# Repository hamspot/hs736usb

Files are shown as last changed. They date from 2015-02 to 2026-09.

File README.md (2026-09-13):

# Ham Spot Inc
##  HS-736USB
http://hamspot.com/33-prod-hs-736usb

### FT-736R to HRD USB Interface
The Yaesu FT-736R remains a popular satellite ground station transceiver.  However some modern computer software is not compatible with the CAT interface on the FT-736R.  Ham Radio Deluxe, in particular, does not support the FT-736R.  Ham Radio Deluxe does support the Yaesu FT-847 which has similar features.  We can solve this incompatibility by programming a CAT interface to present a FT-847 to the PC and emulate the new commands not supported on the FT-736R.  

Features not present on the FT-736R are ignored.  Memory channels are not supported and the radio must be set to VFO, also satellite mode must be set to VFO, before enabling CAT control of the radio.  1240 MHz is mapped to 240 MHz because the FT-847 does not have 4 MHz digits.

### Credits
A short history, archived Comcast pages, and the original downloads are in **[Archives/README.md](Archives/README.md)**.

The concept was developed by Dave, KA6BFB in 2010 (Windows VB proof of concept, virtual serial ports): [Archives/Software.md](Archives/Software.md).

The hardware version was developed by Chuck, N6BIL (PIC18F14K50, GPL source and Eagle CAD): [Archives/Hardware.md](Archives/Hardware.md).

Ham Spot Inc based the HS-736USB on their great work and thanks them immensely for their hard work on solving a challenging problem! The goal of Ham Spot Inc is that if this interface is popular we will develop similar interfaces for other older rigs which are also not supported by HRD. Specifically in mind are the FT-757GXII, FT-890 and various Icom and Kenwood radios. There will likely be firmware updates to this hardware available on the http://hamspot.com/ website in the future. If you have a PIC programmer the chip has been socketed to allow you to flash new firmware or easily replace the device. If not, there will be made available an inexpensive preprogrammed chip that you can plugin to upgrade the firmware or convert the FT-736USB to another model Yaesu rig as they become supported.

### Arduino / ATmega328P port

An Arduino Uno/Nano port of the CAT translator lives in **[Arduino/](Arduino/)**. It keeps the PIC 847↔736 mapping, adds native-736 passthrough (pin A1 or a CAT opcode), PTT/band GPIO, and an S-meter PWM. The PIC firmware in `Firmware/` is unchanged.

```
arduino-cli compile --fqbn arduino:avr:nano Arduino/firmware
cd Arduino && test/run_suite.sh
```

See `Arduino/README.md`, `Arduino/docs/WIRING.md`, and `Arduino/docs/PROTOCOLS.md`. Operating manuals for both the PIC cabinet and the Arduino port are in [`Manual/`](Manual/).

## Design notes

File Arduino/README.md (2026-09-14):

# Arduino / ATmega328P port

Drop-in replacement for the PIC18F14K50 HS-736USB on an Arduino Uno or Nano: the PC speaks **Yaesu FT-847 CAT** (or native **FT-736R** CAT); the box drives the FT-736R CAT jack at 4800 8N2 TTL.

The original PIC firmware, Eagle files, and manual stay in `Firmware/`, `Hardware/`, and `Manual/` at the repo root. This directory is GPL-3 like the rest of the project (N6BIL translator in `Firmware/Source/main.c`).

## Build

```
arduino-cli compile --fqbn arduino:avr:nano Arduino/firmware
arduino-cli upload --fqbn arduino:avr:nano -p /dev/ttyUSB0 Arduino/firmware
```

From this directory, `firmware` is enough. Libraries: **AltSoftSerial**, **Wire**. LCD is a bare HD44780 on an MCP23017 (default) or MCP23008 (`-DHS736_MCP=8`), not an I2C backpack. `-DHS736_MCP=0` omits LCD, encoder, and I2C. See `docs/WIRING.md`.

Host: **4800 8N2**, no handshake. Default dialect is FT-847 (Hamlib `-m 1001`). Pin **A1** low, or CAT `A5 73 36 02 FC`, selects native 736 (`-m 1010`).

- Operating manual (PDF, with the PIC booklet): `../Manual/HS-736USB-Operating-Manual.pdf`
- Wiring: `docs/WIRING.md`
- 847 vs 736 dialects: `docs/PROTOCOLS.md`
- Radio connectors (manual errors): `docs/CONNECTIONS.md`
- Design notes: `PLAN.md`

```
Arduino/test/run_suite.sh
Arduino/test/run_suite.sh /dev/ttyUSB0
```

Run the suite from the `Arduino/` directory (paths are relative to that folder).

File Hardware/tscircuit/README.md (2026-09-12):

# HS-736USB Nano carrier (tscircuit)

Arduino Nano plugs into `JP_L` / `JP_R`. This board is the I/O carrier
(CAT, PTT MOSFET, RCA sense, dialect jumper, LCD, band, PWM). The MCU
is not redrawn.

CAT DIN pin 6 (+13.8 V) is not connected. Power is Nano USB 5 V.

## CLI

IndianaDell installs tscircuit under `~/.local` (`bin/tsci` runs `node`
on `cli.mjs`). The npm shebang is bun, and node cannot load `.tsx`.

From this directory, use the project CLI with bun:

```bash
BUN=/tmp/bunpkg/node_modules/bun/bin/bun.exe
# npm install --prefix /tmp/bunpkg bun  (Linux binary is named bun.exe)

"$BUN" node_modules/tscircuit/cli.mjs check netlist
"$BUN" node_modules/tscircuit/cli.mjs check schematic-placement
"$BUN" node_modules/tscircuit/cli.mjs check placement
"$BUN" node_modules/tscircuit/cli.mjs build --pcb-svgs --schematic-svgs --kicad-project
"$BUN" node_modules/tscircuit/cli.mjs check shorts
inkscape dist/index/pcb.svg --export-type=png --export-filename=dist/index/pcb.png --export-dpi=1200
inkscape dist/index/schematic.svg --export-type=png --export-filename=dist/index/schematic.png --export-dpi=1200
```

Do not `tsci push` or order boards unless asked.

`<schematicsheet>` is omitted on purpose: with it, `kicad_sch` export
is a hierarchical stub (`main.kicad_sch` never written). Sections
still group the schematic.

Known warnings: builtin symbols missing `{REFDES}` text; SOD-123 has
no 3D model on the tscircuit CDN.

Outputs: `dist/index/pcb.png`, `dist/index/schematic.png`,
`dist/index/kicad/`.

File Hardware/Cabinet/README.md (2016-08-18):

# Laser Cut or 3D Printed Cabinet
Inside dimensions 28.73mm x 16mm x 43.73mm

* v1 is Hammond project enclosure.
* v2 is .125" Laser cut acrylic or hardboard.
* v2.1 is a 3D printed case.

json files are for basic dimensions and were generated with http://www.makercase.com/
svg or ai files have been edited to include holes for panel connectors, screws, feet, etc.

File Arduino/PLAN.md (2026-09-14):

# HS-736: PIC18F14K50 → ATmega328 Arduino port

Port [hamspot/hs736usb](https://github.com/hamspot/hs736usb) so an ATmega328P Arduino (Uno/Nano class) sits between a PC and a Yaesu FT-736R: the PC talks **FT-847 CAT** (read/write, Hamlib/HRD/SatPC32), the box translates and drives the **FT-736R CAT** jack (mostly write-only frequency/mode; squelch and S-meter can be read).

Original firmware is the behavioral spec. [Hamlib](https://github.com/Hamlib/Hamlib) `rigs/yaesu/ft847.c` and `ft736.c` are the protocol reference (local copy: `/home/user/Documents/Hamlib`).

License: original CAT translator in `Firmware/Source/main.c` (`To736` / `ProcessIO`, Albert C. Jones / N6BIL, 2010) is **GPL-3**. This port is a derivative and stays GPL-3. Microchip’s USB stack in that file is **not** copied.

---

## What the PIC actually does

USB CDC (VID 0x04D8 / PID 0x000A, generic CDC) ↔ PIC UART TTL:

| PIC pin | Function |
| --- | --- |
| RB7 | UART TX → radio S-OUT pad |
| RB5 | UART RX ← radio S-IN pad |
| RC0/RC1 | LEDs |
| — | Radio UART **fixed 4800**, 8 data. Host USB baud is independent (CDC). |

`ProcessIO()` is the whole product (excerpt in `upstream/ProcessIO-excerpt.c`):

1. Collect host bytes into a 5-byte Yaesu block (`cmd[0..3]` params, `cmd[4]` opcode).
2. **Reads** (never go to the 736): `0x03` / `0x13` / `0x23` freq+mode, `0xE7` RX status, `0xF7` TX status — reply from RAM caches.
3. **Writes** translated to the 736, 5 bytes, wait for TX empty. PIC used **no** 50–200 ms inter-byte delay; this port does (CAT spec).
4. PIC forwarded UART bytes from the 736 to USB. v1 of this port does **not** splice 736 frames onto the 847 stream.

Caches default to 145.0000 MHz FM (`{0x14,0x50,0x00,0x00,0x08}`).

On **CAT ON** (`0x00`) the adapter also forces 145.0000 + FM onto the 736 so host and radio start aligned. CAT ON on the 736 **locks the front panel**.

---

## Protocol (Hamlib + PIC)

Both radios use 5-byte blocks, opcode last, 4800 8N2. FT-736 manual: **50–200 ms between bytes**. Hamlib: `write_delay` 50 ms (847) / 30 ms (736).

### Opcode map (host 847 → radio 736)

| Host opcode | Meaning (ft847.c) | Action |
| --- | --- | --- |
| `00` | CAT ON | Send as-is; then set cached main freq (`01`) and FM (`08 00 00 00 07`) |
| `80` | CAT OFF | Send as-is |
| `08` / `88` | PTT on / off | Send as-is; update TX/RX status cache |
| `01` | Set main freq | Cache 4 BCD bytes; 23 cm remap; send opcode `01` |
| `11` | Set SAT RX freq | Cache; remap opcode **`1E`** (736 full-duplex RX freq) |
| `21` | Set SAT TX freq | Cache; remap opcode **`2E`** |
| `03` / `13` / `23` | Get freq+mode main / sat RX / sat TX | Reply 5 bytes from cache |
| `07` / `17` / `27` | Set mode main / sat RX / sat TX | Forward; store mode in cache byte 4. 736 has no AM/CWR |
| `4E` | Sat mode ON | Remap to **`0E`** (736 “full duplex on”) |
| `8E` | Sat mode OFF | Send `8E`; restore main freq with `01` |
| `09` | Repeater shift (HRD/PIC) | `cmd[4] = cmd[0]` then send (`09` minus, `49` plus, `89` simplex) |
| `49` / `89` | Repeater plus / simplex (Hamlib 847) | Forward as-is. 736 simplex is **`89` not `88`** (`88` is PTT off) |
| `0A` | CTCSS/DCS mode | `2A` (847 ENC/DEC) → opcode `0A`; `0A` (847 DCS) → **drop** (PIC sent `00` = CAT ON; that is a bug); `4A`/`8A` forwarded as opcode |
| `0B` | CTCSS tone | Opcode **`FA`**; index PIC `Tone[38]`. If `cmd[0] > 31`, index `cmd[0]-26`. Clamp if out of range |
| `E7` / `F7` | Get RX / TX status | Reply from cache; do **not** forward as 847 status |
| `F9` | Repeater offset | Forward as-is (736 supports it; PIC dropped it) |
| `1A`/`2A`/`1B`/`2B`/`0C`/`1C`/`2C` | Sat CTCSS / DCS | Drop (no 736 DCS; sat CTCSS later) |

BCD frequency is 8 packed digits, **10 Hz units**, MSB first (Hamlib `to_bcd_be(cmd, freq/10, 8)`).

### 23 cm (1240 MHz)

FT-847 has no 4th MHz digit, so the host shows **240 MHz**. PIC: if `cmd[0]` is `0x24`..`0x30`, add `0xA0` on the **radio copy only** (`0x24` → `0xC4`). Cache returned to the PC stays 240 MHz.

Hamlib native 736 uses `(cmd[0] & 0x0f) | 0xc0` after encoding the true 1.24 GHz value (`0xC2 0x40 …` for 1240.0000). **v1 matches PIC**. Treat Hamlib’s encoding as a 23 cm bench check.

### Status reads

FT-736 **cannot** return frequency or mode. Hamlib `ft736_get_freq` is cache-only.

736 **can** return meters: after `E7`/`F7` it sends five bytes (four copies of squelch or S-meter plus echoed opcode).

FT-847 status is **one** byte:

- `E7` RX: bit7 = squelch closed (DCD off), bits0–4 = S-meter dots
- `F7` TX: bit7 = 1 means RX (`PTT_OFF`), bits0–4 = PO/ALC

v1 replies (Hamlib + HRD):

- `03`/`13`/`23`: 5-byte cache (BCD + mode)
- `E7`/`F7`: 5-byte buffer, **byte0 847-coded** (PIC PTT/squelch bits). Extra four bytes keep HRD happy; Hamlib reads 1 byte then flushes.

Unknown host opcodes: drop. Do not echo garbage to the 736.

### Framing

5-byte assembler: append host bytes; dispatch at 5; keep remainder. If a gap **> 250 ms**, discard partial frame (CAT inter-byte max is 200 ms — protocol timeout, not a poll loop).

---

## Bugs in the PIC firmware

Evidence is `upstream/ProcessIO-excerpt.c` (from hamspot `Firmware/Source/main.c`). These are defects in the translator, not “736 limitations.” This port fixes the ones marked **fixed**.

### 1. DCS ON is rewritten as CAT ON — **fixed**

```
cmd[4] = cmd[0];
if (cmd[0] == 0x2A) cmd[4] = 0x0A;   /* 847 ENC/DEC -> 736 TSQL */
if (cmd[0] == 0x0A) cmd[4] = 0x00;   /* 847 DCS ON  -> opcode 00 */
To736();
```

FT-847 DCS on is `{0x0A, 0x00, 0x00, 0x00, 0x0A}` (Hamlib `FT_847_NATIVE_CAT_SET_DCS_ON_MAIN`). The PIC copies byte 0 into the opcode, then the second `if` overwrites that opcode with **`0x00` (CAT ON)**. The 736 has no DCS; the harm is not “ignore DCS,” it is **re-asserting CAT**, which locks the front panel again. This port **drops** 847 DCS instead of sending `00`.

### 2. `cmd[10]` overflows on a 64-byte USB packet — **fixed**

`cmd` is 10 bytes. `getsUSBUSART(..., 64)` can return up to 64. The copy loop is `cmd[psn] = RS232_Out_Data[x]; ++psn` with no cap. One full CDC packet writes off the end of `cmd` (and into whatever follows in `.udata`). This port accumulates one byte at a time into a 5-byte frame buffer.

### 3. At most one CAT command per USB packet; leftover 5-byte commands stall — **fixed**

After copying the whole packet, it dispatches **once** (`if (psn > 4)`), then:

```
if (psn > 5)
    for (x = 0; x < (psn - 5); ++x) cmd[x] = cmd[x+5];
if (psn > 4) psn = psn - 5;
RS232_Out_Data_Rdy = 0;
```

A 10-byte packet (two Yaesu blocks) runs the first command, rotates the second into `cmd[0..4]` with `psn == 5`, then **clears the “data ready” flag**. The second command sits until **another** USB packet arrives and the copy loop runs again. Hamlib usually sends one 5-byte block per write, so this often works; HRD bursts and back-to-back `rigctl` can stall a command. This port dispatches every complete 5-byte frame in the same `loop()`.

### 4. CTCSS `Tone[x]` has no range check — **fixed**

```
if (cmd[0] > 31) x = cmd[0] - 26;
else x = cmd[0];
cmd[0] = Tone[x];   /* Tone[38] */
```

Any host byte `>= 0x40` (64) yields `x >= 38` and reads off the end of `Tone[]`. This port drops the command if the index is out of range.

Related mismatch (not a bounds bug): the PIC treats byte 0 as an **HRD-style index** (0…31, then skip 26). Hamlib `ft847_set_ctcss_tone` sends **Yaesu CAT tone codes** (`0x3F`, `0x39`, … `0x00`), not 0-based indices. v1 keeps the PIC table so HRD behavior is unchanged; Hamlib CTCSS frequencies will still be wrong until a later Hamlib-code map is added. That is documented, not silently “fixed.”

### 5. No 50–200 ms inter-byte gap on the radio UART — **fixed**

`To736()` waits only for `TXSTA` shift-complete, then sends the next byte immediately. The FT-736R manual requires **50–200 ms between bytes** of a command block. Hamlib uses `write_delay` 30–50 ms for the same reason. Field units often still keyed the radio; this port enforces 50 ms because the spec says so, not because we guessed.

### 6. Radio RX is spliced onto the FT-847 USB stream

```
if (mDataRdyUSART()) {
    USB_Out_Buffer[NextUSBOut] = getcUSART();
    ++NextUSBOut;
    USB_Out_Buffer[NextUSBOut] = 0;
}
```

Any byte the 736 emits (squelch/S-meter replies, AQS, noise) is forwarded to the PC **in the middle of the 847 session**. Hamlib 847 then sees extra bytes before/after a 1-byte `E7` or a 5-byte `03` and can desynchronize. `NextUSBOut` is also incremented with **no cap** against `USB_Out_Buffer[]`. This port **discards** radio RX in v1 (freq/mode are cached; we do not query 736 `E7`/`F7` yet).

### 7. Hamlib repeater-shift opcodes `49` / `89` are ignored

PIC only handles opcode **`09`**, then replaces it with `cmd[0]` (HRD: minus/plus/simplex in byte 0). Hamlib 847 sends the shift **as the opcode**: `09` minus, `49` plus, `89` simplex (`ft847_set_rptr_shift`). Plus and simplex therefore never reach the 736. If HRD ever put **`88`** in byte 0 (736 manual typo for simplex; Hamlib 736 notes that `88` is PTT off), the PIC would send PTT off. This port forwards Hamlib `49`/`89` as-is and keeps the PIC `09`+param path.

### 8. CAT ON / sat-off clobber `cmd[]` after `To736()`

CAT ON sends the host `00` block, then **overwrites** `cmd[]` with cached freq and FM and sends those too. That is intended. Sat-off (`8E`) does the same for a follow-up `01`. Harmless if `To736` is synchronous (it is). Noted so the port’s three-frame result struct is not mistaken for a PIC bug.

### What we did not treat as bugs

- Caching freq/mode instead of reading the 736 — the radio cannot return them.
- Dummy `E7`/`F7` 5-byte replies — design for HRD; byte 0 happens to match 847 PTT/squelch bits.
- Dropping memory, AQS, DCS, sat CTCSS `1A`/`2A` — original README / no 736 feature.
- 23 cm `+ 0xA0` vs Hamlib `(bcd & 0x0f) | 0xc0` — two encodings; PIC’s is what HS-736USB shipped. v1 keeps PIC; bench on a 1.2 GHz module before changing.

---

## Hardware (ATmega328P)

The 328 has **one** hardware USART. On Uno/Nano that USART is the USB-serial bridge to the PC.

See `docs/WIRING.md` (Arduino, including accessory GPIO) and `docs/CONNECTIONS.md` (every FT-736R jack, with diagrams; CAT/DATA manuals are often wrong). Host settings: **Yaesu FT-847, 4800, 8N2, no handshake**.

Accessory GPIO (not 847 CAT): D2 PTT MOSFET (CAT PTT **or** A0 RCA sense, active low), D4–D7 one-hot 50/144/220/430, D10 CAT BUSY in, D3 S-meter PWM from real 736 `F7` polls (also cached into host `E7`). Optional MCP23017 or MCP23008 on A4/A5 (`HS736_MCP`): bare HD44780 + encoder. D13 dialect LED. **A1** (PCINT): HIGH = USB speaks FT-847, LOW = native FT-736. See `docs/PROTOCOLS.md` and `docs/WIRING.md`.

---

## Firmware layout

```
PLAN.md
README.md
LICENSE
upstream/                 # original README, LICENSE, ProcessIO excerpt
firmware/                 # Arduino sketch (folder name = sketch name)
  firmware.ino
  cat_frame.{h,cpp}
  cat_map.{h,cpp}
  radio_uart.{h,cpp}
docs/WIRING.md
docs/CONNECTIONS.md          # FT-736R front/rear pinouts + diagrams
docs/CAT.md
test/golden_vectors.py
test/test_cat_map.c
test/README.md
```

`loop()`:

1. Drain `Serial` into the frame assembler; on complete frame, dispatch.
2. Reads: write reply to USB.
3. Writes: queue radio bytes with 50 ms between bytes (FT-736 CAT spec).
4. Drain radio RX; v1 discards. Do not splice 736 frames onto the 847 stream.

---

## Testing

Host (no Arduino): `test/test_cat_map.c` + `test/golden_vectors.py`.

On hardware without the 736: `rigctl -m 1001 -r /dev/ttyUSB0 -s 4800` (Hamlib FT-847). After `F`/`M`, `f`/`m` should return the cache; `t` should not time out.

On the radio: CAT LED, VFO + sat VFO as in the original README.

---

## Out of scope (v1)

- Memory channels
- AQS / digital messages
- DCS
- Replacing Hamlib’s FT-736 backend (this box **is** an 847)
- Custom USB VID/PID
- Mega / 32U4 / ESP32
- New PCB

---

## Key decisions

| Decision | Why |
| --- | --- |
| Pretend 847 to the PC, 736 to the radio | Same product as HS-736USB; Hamlib 847 (`-m 1001`) has sat VFOs and reads |
| Faithful PIC opcode map, plus `F9` and Hamlib `49`/`89` | Known HRD behavior; Hamlib 736 confirms `1E`/`2E`/`0E`/`FA` |
| Cache freq/mode; 5-byte `E7`/`F7` with 847-coded byte0 | 736 has no freq read; HRD wanted 5 bytes; Hamlib 847 reads 1 byte then flushes |
| Hardware USART = PC, AltSoftSerial 8/9 = radio | Only one USART on 328; USB is the busy polling side |
| Host locked to 4800 8N2 | Uno UART baud is the CDC baud; 847/736 native rate |
| 50 ms radio inter-byte delay | FT-736 CAT spec 50–200 ms; PIC omitted it |
| Drop 847 DCS (`0A`/`0A`) instead of sending CAT ON | PIC bug: it rewrote the opcode to `00` |
| GPL-3, no Microchip USB sources | Translator is GPL; USB stack is not ours |

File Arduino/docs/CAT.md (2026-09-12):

# CAT opcode map

Default host dialect is FT-847 (Hamlib `-m 1001`). Pin **A1** low switches the USB dialect to native FT-736R (`-m 1010`). The radio is always driven with 736 CAT. Full tables and “what if I use the wrong dialect”: `docs/PROTOCOLS.md`.

Physical CAT jack: `docs/CONNECTIONS.md` and `docs/WIRING.md` (AMSAT pin numbers; some manuals are wrong).

See `PLAN.md` for the full opcode table, 23 cm mapping, status-byte layout, and the **Bugs in the PIC firmware** section.

Quick reference:

| Host (847) | Radio (736) |
| --- | --- |
| `00` CAT on | `00` then cached `01` freq and `07` FM |
| `80` CAT off | `80` |
| `08` / `88` PTT | same |
| `01` set freq | `01` (23 cm: first BCD `+ 0xA0` if 240–300 MHz) |
| `11` / `21` sat freq | `1E` / `2E` |
| `03` / `13` / `23` get freq | cache only (5 bytes) |
| `07` / `17` / `27` mode | same opcodes |
| `4E` sat on | `0E` full duplex on |
| `8E` sat off | `8E` then main `01` |
| `09` shift (HRD) | opcode = byte 0 |
| `49` / `89` shift (Hamlib) | forward |
| `0A` CTCSS mode | see PLAN.md; DCS dropped |
| `0B` tone | `FA` + PIC `Tone[]` |
| `E7` / `F7` status | 847: `E7` is last polled 736 S-meter (`F7`) as 847 RX status; `F7` is TX/PTT cache. 736 mode: forwarded to the radio |
| `F9` offset | forward |

Radio bytes are spaced **50 ms** apart (FT-736 manual: 50–200 ms per byte).

User opcode `A5 73 36 <sel> FC`: dialect source `00` jumper, `01` force 847, `02` force 736, `FF` cycle. See `docs/PROTOCOLS.md`.

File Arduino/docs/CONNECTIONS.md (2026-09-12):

# FT-736R connectors

Pinouts for **every** front- and rear-panel connector on the Yaesu FT-736R.

**Do not trust a random photocopy of the operating manual for CAT or DATA.** Some printings number DIN pins with Japanese/Yaesu order instead of IEC 60130, and some print the DATA jack tip/ring backwards. Sources used here are listed at the end of each section. Where sources disagree, both are shown and the one to wire is marked **use this**.

This file is about the **radio**. Arduino adapter wiring is in `docs/WIRING.md`.

---

## Manual errors (read this first)

| What is wrong | What is true | Source |
| --- | --- | --- |
| CAT pin numbers in some FT-736R manuals and an old Yaesu application note | Pin 1 GND, 2 serial **in** (to radio), 3 busy, 4 serial **out** (from radio), 5 NC, 6 +13.8 V. Pins are **not** numbered sequentially around the shell. | AMSAT W6SHP note |
| European DIN numbering vs Yaesu drawing | Same signals; the **printed pin numbers** on a European DIN drawing may not match the Yaesu drawing. Identify pins by the **keyway + AMSAT map** below, not by a number printed in a manual. | French OM translation note |
| DATA IN/OUT tip/ring reversed on some manuals | **Tip = received data (from radio). Ring = transmit data (to radio). Sleeve = GND.** | AMSAT W6SHP note; English OM text (when it matches) |
| CAT “S.IN / S.OUT” named from the TNC’s point of view | On the **radio**: S.IN is data **into** the 736, S.OUT is data **out of** the 736. Adapter TX goes to S.IN. | HS-736USB pads; AMSAT |
| 736 simplex CAT opcode `88` in some 736 charts | `88` is **PTT off**. Simplex is `89`. | Hamlib `ft736.c` |
| MH-31B8 “just works” in the 8-pin jack | Stock mic is **MH-1B8**. An MH-31B8 needs an **internal** rewire (Yaesu service note); the 8-pin shell is the same family, the mic PCB is not. | mods.dk / Yaesu MH-31 note |

---

## Rear panel map (left to right, typical)

Viewed from behind the radio. Optional antenna jacks exist only if the matching band module is installed.

```
  [ DC pigtail from internal PSU ]     [ 13.8 V DC inlet (white) ]
  [ GND screw ]
  [ CAT  6-pin DIN 240° ]
  [ STBY 5-pin DIN 180° ]
  [ KEY  6.35 mm TRS ]
  [ EXT SPKR  3.5 mm TS ]
  [ PTT  RCA ]
  [ DATA IN/OUT  3.5 mm TRS ]
  [ FUSE ]
  [ AC 3-pin ]
  [ ANT 430  type N ]     [ ANT 144  SO-239 ]
  [ ANT opt lower-left    type N or SO-239 ]   [ ANT opt lower-right  SO-239 ]
```

Lower-left optional jack is 1.2 GHz (type N) **or** 50/220 (SO-239). Lower-right optional is 50 or 220 (SO-239). The 1.2 GHz module fits only the lower-left compartment (rear view).

---

## CAT — 6-pin DIN 240° (270° key)

TTL, 4800 bit/s, 8 data, no parity, **2 stop bits**. This is the jack HS-736 uses.

### Pin map — **use this**

| Pin | Radio name | Direction | Notes |
| --- | --- | --- | --- |
| 1 | GND | — | Adapter GND |
| 2 | S.IN / serial data in | **into radio** | Arduino **D9 TX** (idle high TTL) |
| 3 | Busy | from radio | Adapter **D10**. INPUT_PULLUP; LOW = squelch open / carrier (front-panel BUSY). Measure 5 V first. |
| 4 | S.OUT / serial data out | **out of radio** | Arduino **D8 RX** |
| 5 | NC | — | No connect |
| 6 | +13.8 V | from radio | **Do not** feed the Arduino 5 V pin |

### Diagram — rear of **male** plug (pins toward you, cable away)

AMSAT: pins are **not** numbered sequentially. Keyway orientation as they drew it:

```
            rear of male 6-pin DIN plug

                 3           1
                       6
                 5           4
                       2

            1 GND              4 S.OUT  (radio TX, to adapter RX)
            2 S.IN  (radio RX, from adapter TX)
            3 BUSY             5 NC
            6 +13.8 V          (do not use for Arduino power)
```

Looking **into the radio’s CAT socket** (holes), the pattern is mirrored left-right.

### Arduino (this project)

```
  PC USB CDC 4800 8N2
       |
  ATmega328 USART0
       |
  D9 TX  ---------------->  CAT pin 2  S.IN
  D8 RX  <----------------  CAT pin 4  S.OUT
  GND    -----------------  CAT pin 1  GND
  (no wire)                 CAT pin 6  +13.8 V
```

---

## STBY — 5-pin DIN 180° (amplifier ground-on-TX)

Open-collector / relay **ground when that band is transmitting**. Connect pin 1 to the amplifier chassis. Do not put 13.8 V or RF on these pins.

| Pin | Function |
| --- | --- |
| 1 | GND |
| 2 | STBY 430 MHz (ground on TX) |
| 3 | STBY for the module on **J5011** (50 / 220 / 1200 MHz, depending what is fitted) |
| 4 | STBY 144 MHz |
| 5 | STBY for the module on **J5010** (50 / 220 MHz) |

Operating manual table (same numbers):

| Amplifier band | STBY pin |
| --- | --- |
| 430 MHz | 2 |
| Band module at J5011 | 3 |
| 144 MHz | 4 |
| Band module at J5010 | 5 |

### Diagram — 5-pin DIN 180°, looking **into the radio socket**

```
            1                 2
                 4       5
                      3
```

(IEC 60130-9 180° layout. If your plug’s key does not match, go by continuity to chassis on pin 1, not by a photocopied number.)

---

## KEY — 6.35 mm TRS (stereo)

| Contact | Function |
| --- | --- |
| Tip | Dash / straight-key | Closed to sleeve keys the TX (or dash if Keyer Unit B is on) |
| Ring | Dot (paddle) | Dual-lever paddle only |
| Sleeve | GND | |

Open-circuit about **+4.5 V**, closed **~2 mA**.

```
        6.35 mm TRS plug
    =========()===========
     tip   ring    sleeve
      |      |        |
    DASH    DOT      GND
    (or straight key ---+--- sleeve)
```

**Never use a mono 2-conductor plug.** A mono barrel shorts ring to sleeve and can hang the optional iambic keyer or the KEY line. For a straight key, use a **stereo** plug and leave the ring unconnected.

If Keyer Unit B is **off** (or not installed), a straight key on tip–sleeve is enough.

---

## EXT SPKR — 3.5 mm TS (mono)

| Contact | Function |
| --- | --- |
| Tip | Speaker audio (follows AF gain) |
| Sleeve | GND |

4–8 Ω (SP-767 or similar). Inserting a plug does **not** mute the front PHONES jack; **PHONES** mutes the internal / this speaker.

```
     3.5 mm TS
    =====()====
     tip  sleeve
      |     |
     AF    GND
```

---

## PTT — RCA (phono)

Parallel with the front **MOX** button. Ground the center pin to transmit.

| Contact | Function |
| --- | --- |
| Center | PTT (active low) |
| Shell | GND |

Open **8 V**, closed **8 mA**. Packet TNC or footswitch. MOX and the mic PTT close this same line.

The HS-736 adapter can **sense** this jack on **A0** (Y-cable) and pass it through to the D2 MOSFET. **8 V will kill a 328 pin** — use the 22 kΩ + 5.1 V zener in `docs/WIRING.md`. CAT PTT still keys the radio over serial; the MOSFET follows CAT **or** this sense line.

```
      RCA
     ( o )   center = PTT
     (===)   shell  = GND
```

---

## DATA IN/OUT — 3.5 mm TRS (packet / AFSK)

Direct FM modulator / discriminator. **No** pre- or de-emphasis. FM mode only at this jack. Good for 1200 baud AFSK; 9600 baud needs internal taps (G3RUH / W6SHP).

### Pin map — **use this** (AMSAT + English OM text)

| Contact | Function | Level |
| --- | --- | --- |
| **Tip** | DATA **OUT** — received audio **from the radio** (RD) | ≤ 200 mVrms, 10 kΩ |
| **Ring** | DATA **IN** — AFSK **to the radio** (TD) | 30 mVrms, 600 Ω |
| **Sleeve** | GND | |

```
        3.5 mm TRS
    =========()===========
     tip   ring    sleeve
      |      |        |
    RD     TD        GND
   (from   (to
    radio)  radio)
```

Some manuals swap tip and ring in the **drawing** even when the text is correct. If a TNC wiring “from the book” has no RX audio, swap tip and ring **once** before changing anything else.

PTT for packet is the **RCA**, not this jack.

---

## 13.8 V DC

| Connector | Role |
| --- | --- |
| White 13.8 V **inlet** | External DC (E-736 cable) **or** the pigtail from the internal switcher |
| Pigtail from internal PSU | 13.8 V at up to 8 A. Plug it into the white inlet for AC-mains use |
| GND screw | Station earth — short, fat, to a real ground |

Do not power the Arduino from CAT pin 6. Do not back-feed the internal PSU.

---

## AC mains and fuse

3-pin AC inlet. Fuse rating must match the **voltage label** on the rear (100 / 117 / 220 / 234 V versions exist). Confirm the label before plugging in.

---

## Antenna jacks

All 50 Ω unbalanced.

| Jack (rear view) | Connector | Band |
| --- | --- | --- |
| Upper left | Type **N** | 430 MHz (always present) |
| Upper right | **SO-239** (type M) | 144 MHz (always present) |
| Lower left (optional) | Type **N** if 1.2 GHz module; **SO-239** if 50 or 220 | Module in that bay only |
| Lower right (optional) | **SO-239** | 50 or 220 MHz module |

```
   rear of radio (typical)

      [ N 430 ]     [ SO-239 144 ]
      [ opt N/SO ]  [ opt SO-239 ]
```

1.2 GHz module: lower-left bay only.

---

## Front panel connectors

### MIC — 8-pin locking round (male on the mic)

Stock mic: **MH-1B8**. Desk: **MD-1B8**. Impedance 200 Ω–10 kΩ, 600 Ω nominal.

Yaesu 8-pin family used on FT-736 / FT-726 / FT-747 / FT-757 / FT-847 (W9DUP compilation). **Pin 2 is earth on the 736**, not +5 V (later HF radios put +5 V on pin 2).

| Pin | FT-736 / MH-1B8 |
| --- | --- |
| 1 | UP |
| 2 | Earth (UP/DOWN common on some mics in this family) |
| 3 | DOWN |
| 4 | FAST scan |
| 5 | Earth |
| 6 | PTT (ground to TX) |
| 7 | Mic screen / earth |
| 8 | Mic audio |

### Diagram — looking **into the radio MIC jack** (holes)

Standard Yaesu 8-pin numbering (pin 8 and 7 at the top):

```
              8           7
          6                   5
          4                   3
              2           1

          8 MIC audio         7 mic GND
          6 PTT               5 GND
          4 FAST              3 DOWN
          2 earth             1 UP
```

An **MH-31B8** is the same 8-pin shell as later radios but **does not** work on a 736 until the mic’s internal PCB is modified (Yaesu). Do not assume pin-for-pin with an unmodified MH-31.

### PHONES — 6.35 mm TRS or TS

| Contact | Function |
| --- | --- |
| Tip | Audio (left, or mono) |
| Ring | Audio (right); on a TS mono plug the ring is unused |
| Sleeve | GND |

4–100 Ω. Stereo or mono headphones. **Inserting a plug cuts the internal speaker and EXT SPKR.**

```
        6.35 mm
    =========()===========
     tip   ring    sleeve
     L     R        GND
```

---

## Front / top controls that are not connectors

Listed so they are not confused with jacks:

| Location | What it is |
| --- | --- |
| POWER, MOX | Front pushbuttons. MOX is in parallel with rear PTT RCA |
| MIC / DRIVE, SQL / TONE, AF / RF | Concentric pots |
| KEYER, VOX GAIN, DELAY | Keyer Unit B and VOX; KEYER must be **out** if using a straight key |
| SAT, AGC | Satellite / AGC. CAT needs VFO + sat VFO, not memory |

---

## HS-736 adapter vs other rear jacks

This firmware only talks to **CAT**. It does not use STBY, KEY, DATA, or MIC.

| You want | Use |
| --- | --- |
| Computer CAT (this project) | CAT DIN, TTL, 4800 8N2 |
| Packet 1200 AFSK | DATA TRS + PTT RCA |
| Packet 9600 | Internal discriminator / varactor taps, not the DATA jack as-is |
| Linear amplifier T/R | STBY DIN, band-specific pin |
| Footswitch / TNC PTT | PTT RCA (or MIC pin 6) |
| CW key | KEY TRS, stereo plug |

---

## Sources

- AMSAT W6SHP, “Note for FT-736 Microsat Mods” — CAT pin correction; DATA tip/ring correction; CAT male-plug map.
- Yaesu FT-736R operating manual (rear-panel chapter) — STBY table, KEY warning, PTT voltages, DATA levels, antenna types, PHONES, MIC impedance. **CAT numbers in some copies are wrong; DATA drawings in some copies are wrong.**
- French OM translation — DIN numbering vs European drawings; STBY pin list; KEY 4.5 V / 2 mA; never use a mono KEY plug.
- Hamlib `rigs/yaesu/ft736.c` — CAT 4800 8N2; simplex opcode `89` not `88`.
- W9DUP *Microphone connectors* compilation — 8-pin map grouping FT-736 with FT-747 / FT-757 / FT-847 (pin 2 earth on 736).
- mods.dk “Modifying the MH-31 for the FT-736R” — MH-31B8 is not drop-in.
- hamspot/hs736usb hardware — TTL S-IN / S-OUT pads, no MAX232.

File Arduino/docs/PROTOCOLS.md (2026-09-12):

# Talking to HS-736: FT-847 vs FT-736R CAT

The adapter sits on USB as a 4800 8N2 CAT port. **Pin A1** (IRQ) selects which language the PC is speaking. It does **not** reset CAT on the radio.

| A1 | Protocol | PC software |
| --- | --- | --- |
| HIGH (open, pull-up) | **FT-847** (default) | Hamlib `-m 1001`, HRD, SatPC32 as FT-847 |
| LOW (jumper to GND) | **FT-736R native** | Hamlib `-m 1010`, programs that speak 736 |

A **pin-change interrupt** on A1 switches immediately and **drops any half-finished 5-byte USB frame** so 847 and 736 bytes are never mixed. Frequency / PTT / sat flags in RAM stay put — flip the switch mid-QSO without sending CAT OFF.

### CAT override (three-way, user opcode)

Jumper is default. A non-Yaesu block can **temporarily** ignore A1:

```
  A5 73 36  <sel>  FC
```

| `<sel>` | Source | Effective dialect |
| --- | --- | --- |
| `00` | **Jumper** | Follow A1 again (IRQ live) |
| `01` | Force **847** | 847 even if A1 is low |
| `02` | Force **736** | 736 even if A1 is high |
| `FF` | **Cycle** | jumper → 847 → 736 → jumper |

Reply is the same 32-byte dump as `… FE` (byte 3 = proto in the low nibble, source in the high nibble). Nothing is sent to the radio.

While forced 847/736, A1 IRQs still **latch** the pin but do **not** change the dialect until:

- CAT `sel=00` / cycle back to jumper, or
- **Double-flip** the jumper: two **debounced** edges within **1 s** (wiggle 1→0→1 or 0→1→0) returns source to jumper and follows the pin.

Bounce: PCINT only marks “dirty”. The pin is sampled after **50 ms** of quiet. A single noisy flip is one qualified edge, not a revert. Two stable flips inside a second cancel a CAT force.

This opcode is accepted in **both** dialects so you can switch without already matching the jumper.

---

## If you speak 736 to an 847-mode adapter (A1 HIGH)

It will **not** NAK. Unknown opcodes are **dropped with no USB error**. Overlap is large enough that simplex can look fine while satellite is silently dead.

### Same opcode — usually works

| 736 command | What happens in 847 mode |
| --- | --- |
| CAT ON `00` | Works, **and** forces 145.000 FM onto the radio (847 CAT-ON extra) |
| CAT OFF `80` | Works (only byte 4 matters) |
| Set main freq `01` | Works |
| Set mode `07` | Works |
| PTT `08` / `88` | Works |
| Repeater `09` / `49` / `89`, offset `F9` | Works |
| Mode sat RX/TX `17` / `27` | Forwarded, but duplex may never have been turned on |

### Native 736 opcodes — **locked out** in 847 mode

| 736 opcode | 847 opcode we expect | Result if you send the 736 form |
| --- | --- | --- |
| Full duplex ON **`0E`** | `4E` (we emit `0E`) | Dropped. Sat never enables |
| Sat RX freq **`1E`** | `11` → `1E` | Dropped |
| Sat TX freq **`2E`** | `21` → `2E` | Dropped |
| Tone **`FA`** | `0B` → `FA` | Dropped |
| CTCSS as opcode `4A`/`8A` | `0A` + param in byte 0 | Dropped |

That is why SatPC32/Hamlib **must** be set to **FT-847** when A1 is high. A 736 driver will move VFO A and PTT and believe duplex is on.

### Reads in 847 mode

`E7`/`F7` are answered from the **dummy 847 cache** (5 bytes). Hamlib 736 would not time out, but DCD/S-meter meaning is wrong. Hamlib 736 does not send `03`/`13`/`23`.

Sharp edge: 736 CTCSS-on `{00,00,00,00,0A}` in 847 mode copies byte 0 into the opcode → **CAT ON** again (front panel re-locks). In 736 mode that same block is passed through as TSQL.

---

## If you speak 847 to a 736-mode adapter (A1 LOW)

847-only opcodes are **locked out**: `4E`, `11`, `21`, `0B`. Sat from HRD/SatPC32 will not work until A1 is high again.

Native 736 sat **does** work: `0E`, `1E`, `2E`, `FA`, `4A`/`8A`/`0A` as opcodes. `E7`/`F7` are sent to the radio and the 5-byte reply is returned on USB (real meter/squelch). CAT ON is a single `00` (no forced 145/FM). Duplex OFF `8E` does not rewrite main VFO.

The state machine still tracks freq/mode/PTT/sat from whatever **did** get through, so you can switch A1 back to 847 and the caches remain.

---

## Opcode map (both modes)

| Opcode | 847 mode (A1 HIGH) | 736 mode (A1 LOW) |
| --- | --- | --- |
| `00` / `80` | CAT on (plus sync freq+FM) / off | CAT on (bare) / off |
| `01` | set main, 23 cm `+0xA0` | pass through; cache 23 cm as 240 MHz |
| `11` / `21` | → `1E` / `2E`, sat freq | **locked** |
| `1E` / `2E` | **locked** | sat RX/TX freq, `sat=1` |
| `07` `17` `27` | set mode | same |
| `08` `88` | PTT | same |
| `4E` | → `0E`, sat on | **locked** |
| `0E` | **locked** | full duplex / sat on |
| `8E` | sat off + restore main `01` | sat off only |
| `0B` | tone → `FA` | **locked** |
| `FA` `4A` | **locked** | pass through |
| `0A` | 847 CTCSS param in byte 0 | pass through as 736 TSQL opcode |
| `E7` `F7` | dummy 847 cache to USB | query radio, 5-byte reply to USB |
| `03` `13` `23` | cache to USB | cache to USB (736 software rarely sends these) |
| `A5 73 36 00 FE` | 32-byte state dump (both modes) | same |

---

## Hardware

```
  A1 --o  INPUT_PULLUP
       |
       +-- optional SPDT or jumper to GND = 736 native

  Open / HIGH = 847 (Hamlib 1001)
  GND  / LOW  = 736 (Hamlib 1010)
```

PCINT on A1 (not INT0/INT1 — those pins are PTT MOSFET and S-meter PWM). Bounce may fire the ISR several times; each edge samples the pin and sets the matching protocol.

Do **not** change PC software baud: both radios are 4800 8N2. Only the opcode dialect changes.

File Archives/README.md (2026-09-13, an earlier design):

# Archives — how HS-736USB got here

This folder holds the pre-Ham-Spot material: Dave KA6BFB’s Windows
proof of concept, Chuck N6BIL’s PIC hardware, and the Comcast pages
that used to host both. The live product tree is still at the repo
root (`Firmware/`, `Hardware/`, `Arduino/`, `Manual/`).

## Narrative

The Yaesu **FT-736R** is still a serious VHF/UHF satellite radio. Its
CAT jack is TTL serial at 4800 8N2, write-mostly, and it locks the
front panel while CAT is on. Ham Radio Deluxe never learned that
dialect. It *did* learn the later **FT-847**.

In **2010**, Dave Dowler **KA6BFB** built a Windows program that sat
between HRD and the radio: HRD thought it was talking to an 847; the
program translated and drove the 736. It needed virtual serial ports
(VSPE or three real COMs) plus a TTL level shifter. He posted it with
**no support**, a setup video, and the installer. That page and zip
are here as [`Software.md`](Software.md).

Chuck **N6BIL** took the same mapping into a **PIC18F14K50** USB box
so the PC saw a CDC serial port and the radio saw native 736 CAT — no
serial-port chaining. He published Eagle files, a HEX, source (GPL),
a Mouser/Digi-Key BOM, and construction videos. That page and the
original downloads are [`Hardware.md`](Hardware.md).

Ham Spot Inc (David L Norris, KG9AE) put N6BIL’s translator in a
Hammond cabinet, wrote a booklet, and sold a short run so the W9CRC
club station — and anyone else stuck with HRD and a 736 — could talk
to the radio. The PIC firmware, Eagle CAD, and that booklet remain in
this repo.

In **2014** KA6BFB wrote that they had given the idea “to all the
world to see and use,” asked only for credit (even fine print), and
after seeing the Ham Spot manual said the description there was
“more than adequate.” He linked the Ham Spot product from his own
page. There is no separate mail from N6BIL in this Gmail account;
his source was already GPL and published.

**v2.0.0** (2026) ports the translator to an Arduino Nano/Uno,
keeps the PIC tree, and adds a 16×2 LCD, dialect switch, PTT/band
GPIO, and a Nano carrier board. The Yaesu-style operating manual
covers both generations.

## Videos (posted on X, 13 Sep 2026)

Thread: [HamSpot HS-736USB / Arduino port](https://x.com/DavidLNorris/status/2098997812826390888)
(@DavidLNorris).

| Who | What | YouTube | X |
| --- | --- | --- | --- |
| KA6BFB | Windows 847→736 translator in use | [watch](https://www.youtube.com/watch?v=7H98FBQZJ_A) | [post](https://x.com/DavidLNorris/status/2099173398702072277) |
| N6BIL | PIC USB hardware (no serial chaining) | [watch](https://www.youtube.com/watch?v=G8I17jarXMw) | [post](https://x.com/DavidLNorris/status/2099173910470087070) |

Chuck’s construction channel (from the 2011 hardware page):
<http://www.youtube.com/user/zdz801>

## Pages in this folder

| File | What it is |
| --- | --- |
| [`Software.md`](Software.md) | KA6BFB Windows emulator (Wayback 11 Jun 2015) |
| [`Hardware.md`](Hardware.md) | N6BIL PIC hardware emulator (Wayback 25 Dec 2011) |
| [`736 Windows Emulator.ZIP`](736%20Windows%20Emulator.ZIP) | KA6BFB installer |
| [`Hex File.zip`](Hex%20File.zip) | N6BIL HEX (`Project 4.hex`) |
| [`Source code package.zip`](Source%20code%20package.zip) | N6BIL PIC sources |
| [`PCB Files.zip`](PCB%20Files.zip) | N6BIL Eagle rev1 |
| [`HRDto736_Driver.zip`](HRDto736_Driver.zip) | Microchip CDC INF + `usbser.sys` |
| [`736R_HRD tester info sheet.doc`](736R_HRD%20tester%20info%20sheet.doc) | N6BIL driver notes |

Unpacked / later copies in the tree:

- PIC HEX and source: [`Firmware/`](../Firmware/)
- Ham Spot Eagle: [`Hardware/Eagle/`](../Hardware/Eagle/)
- Arduino port: [`Arduino/`](../Arduino/)
- Operating manuals: [`Manual/`](../Manual/)
- Nano carrier: [`Hardware/tscircuit/`](../Hardware/tscircuit/)

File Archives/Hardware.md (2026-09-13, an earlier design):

# FT-847 Hardware Emulator for the FT-736R

Archived from Dave KA6BFB’s Comcast page, captured
[25 Dec 2011](https://web.archive.org/web/20111225054335/http://home.comcast.net/~tinkyr/736/N6BIL%20Hardware%20Emulator.htm).
Downloads below point at files already in this folder or at the Ham Spot
copies in the rest of the tree.

Chuck, N6BIL, has implemented a hardware version of the emulator project.
All of the information needed to make your own is available here. The PCB
is available from the Batch PCB company as shown below. The HEX file for
programming the microcontroller is provided, but you will have to arrange
for the programming of the device yourself.

The finished product works extremely well. Frequency corrections for Doppler
shift can be made even while transmitting. Once configured properly,
operation is quite seamless. To use the emulator, connect the emulator to a
USB port and once it is recognized, it will appear as a serial port on the
computer. Go into HRD and select a new connection to an FT-847 at the com
port that corresponds to the emulator and at a port speed of 4800. Press
the connect button, and that’s it!

Most of the modes of the ’847 work with the FT-736. The 847 was also an HF
radio, so obviously the 736 will not accommodate HF frequencies if you try
that. The 736 can also support 220 MHz and 1.2 GHz, which the 847 could
not. You can get 220 operation simply by moving HRD to 220 MHz. 1.2 GHz
operation is just a little more tricky. The 1.2 GHz band is
1240–1299.995 MHz. Since HRD in the 847 mode does not display this range, a
small trick has been incorporated. Drop the 1000 MHz digit and then go to
the frequency you want. For example, to go to 1247.660, go to 247.660 in
HRD.

Another item to look for while in satellite mode is outlined in the 736
manual. The radio cannot transmit and receive with the same band module.
This may result in some confusing situations if you accidentally try this.
If you need to listen on 144 MHz and transmit on 440 MHz and the radio is
already setup in the opposite condition, you will run into the problem when
you try to change one of the bands because you can only change one
frequency at a time and the radio will reject your change because it seems
like you want to have both transmit and receive on the same band. The way
to fix this is simple. Get out of the CAT mode, and press the “REV” button
and this reverses the bands associated with RX and TX. Then reconnect with
HRD and everything will be fine.

Chuck has made some videos along the way for the project construction. They
can be viewed on his YouTube site at
<http://www.youtube.com/user/zdz801>

Here are a few pictures of the completed project.

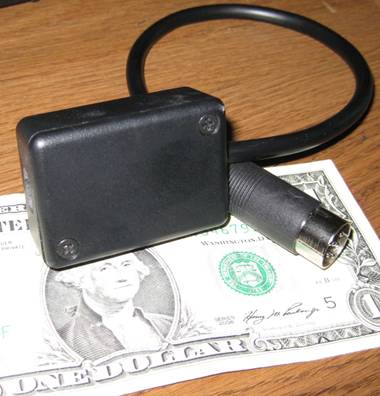
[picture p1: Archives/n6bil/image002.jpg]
N6BIL build

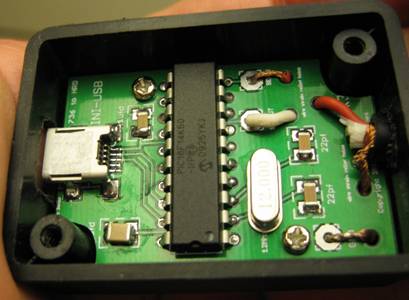
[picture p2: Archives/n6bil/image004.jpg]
N6BIL build, other view


This is Chuck’s implementation (N6BIL).

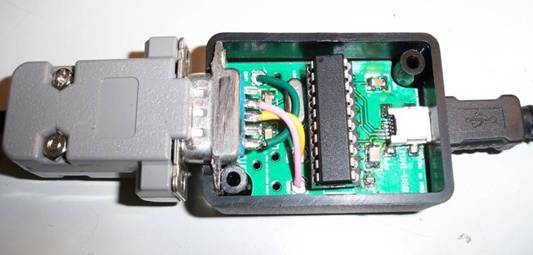
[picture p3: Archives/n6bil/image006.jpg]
KA6BFB DB9 build

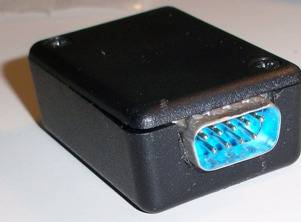
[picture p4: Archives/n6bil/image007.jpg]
KA6BFB DB9 build, other view


These two are my (KA6BFB) version using a DB9 connector.

## Project Related Components

### Schematic

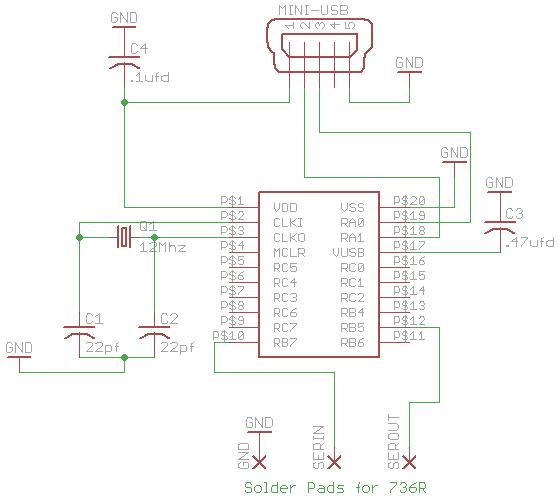
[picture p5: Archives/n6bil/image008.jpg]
N6BIL schematic


Ham Spot CAD for the production board is
[`Hardware/Eagle/HS-736USB.sch`](../Hardware/Eagle/HS-736USB.sch)
and [`Hardware/Eagle/HS-736USB.brd`](../Hardware/Eagle/HS-736USB.brd).
N6BIL’s original Eagle files are in [`PCB Files.zip`](PCB%20Files.zip)
(`736R_HRD rev1.sch` / `.brd`).

### Connection to DIN Plug

As shown in the schematic above, three wires are used to connect with the
736. One is ground and the other two are signals. These signals are already
at TTL levels, so no inversion and level translation is required. A cable
coming out of the box going directly to the 6 pin DIN plug, or a DB9
intermediate connector can be used. Either way, the following must
ultimately happen:

- Pin 10 of the IC must connect to Pin 2 of the DIN Connector
- Pin 12 of the IC must connect to Pin 4 of the DIN Connector
- GND on the PCB must connect to Pin 1 of the DIN connector

The image below is taken from the 736 Manual and shows the pin out of the
DIN connector.

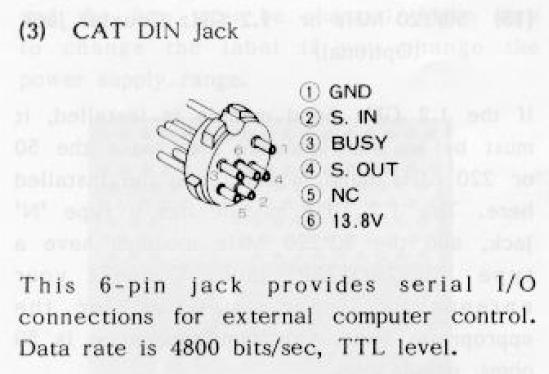
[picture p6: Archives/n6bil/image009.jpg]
FT-736R CAT DIN pinout


The same drawing is Fig. 6 in the operating manual:
[`Manual/figures/fig-cat-din.png`](../Manual/figures/fig-cat-din.png).
Use the AMSAT pin map in [`Arduino/docs/CONNECTIONS.md`](../Arduino/docs/CONNECTIONS.md)
— some printings number the shell differently.

### Bill of Materials

| Part | Value | Device | Package | Comment |
| --- | --- | --- | --- | --- |
| C1 | 22 pF | Cap | 1206 | |
| C2 | 22 pF | Cap | 1206 | |
| C3 | .47 uF | Cap | 1206 | |
| C4 | .1 uF | Cap | 1206 | |
| Q1 | 12 MHz | CRYSTAL | HC49 | Digikey P/N [X1037-ND](http://search.digikey.com/scripts/DkSearch/dksus.dll?Detail&name=X1037-ND) or equivalent |
| U$1 | PIC 18F14K50 | DIP IC | 20 Pin DIP | Digikey P/N [PIC18F14K50-I/P-ND](http://search.digikey.com/scripts/DkSearch/dksus.dll?Detail&name=PIC18F14K50-I/P-ND) \*\*\* |
| X1 | MINI B USB | Connector | UX60-MB-5ST | Digikey P/N [H2959DKR-ND](http://search.digikey.com/scripts/DkSearch/dksus.dll?Detail&name=H2959DKR-ND) |
| | | connector | DIN 6 Pin | DigiKey P/N [CP-1060-ND](http://search.digikey.com/scripts/DkSearch/dksus.dll?Detail&name=CP-1060-ND) |
| BOX | 1551GBK | Enclosure | Hammond 1551GBK | Digikey [HM375-ND](http://search.digikey.com/scripts/DkSearch/dksus.dll?Detail&name=HM375-ND), Mouser 546-1551GBK, All Electronics 1551-GBK |
| PCB | | | | [Batch PCB product 54406](http://www.batchpcb.com/index.php/Products/54406) (historical; Batch PCB is gone) |

Ham Spot’s BOM for the later board is [`Hardware/Eagle/bom.txt`](../Hardware/Eagle/bom.txt).
Enclosure artwork is under [`Hardware/Cabinet/`](../Hardware/Cabinet/).

\*\*\* Note. If you cannot program the device yourself, Chuck will program
the device for you at no charge. Just send the device to Chuck with return
postage to Chuck Jones, 1110 Christopher Court, Hollister, CA, 95023.

N6BIL also has set up a project parts list at Mouser. The link is
<https://www.mouser.com/ProjectManager/ProjectDetail.aspx?AccessID=5f0043a1df>

N6BIL’s file describing driver selection
[here](736R_HRD%20tester%20info%20sheet.doc).

### Drivers

ZIP file containing driver files [here](HRDto736_Driver.zip)
(`mchpcdc.inf`, `usbser.sys`).

### PCB Files

Eagle PCB files [here](PCB%20Files.zip) in case you want to make your own
PCB. Otherwise simply purchase the finished PCB from Batch PCB as described
in the Bill of Materials above.

Ham Spot production CAD (not the N6BIL rev1 zip):
[`Hardware/Eagle/`](../Hardware/Eagle/).

### Software

All that is required is the HEX file to program the microcontroller. The
HEX file is available [here](Hex%20File.zip) (`Project 4.hex`). The HEX
file is all that is required to program the microcontroller.

The Ham Spot binary is [`Firmware/HS-736USB.hex`](../Firmware/HS-736USB.hex).

If you want to look at all the original source code, it is available
[here](Source%20code%20package.zip).

The same sources live unpacked in [`Firmware/Source/`](../Firmware/Source/).

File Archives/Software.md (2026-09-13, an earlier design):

# FT-847 Windows Emulator for the FT-736R

Archived from Dave KA6BFB’s Comcast page, captured
[11 Jun 2015](https://web.archive.org/web/20150611033646/http://home.comcast.net/~tinkyr/736/KA6BFB%20Windows%20Emulator.htm).
The installer is [`736 Windows Emulator.ZIP`](736%20Windows%20Emulator.ZIP)
in this folder.

This software will enable you to use the FT-736R with Ham Radio Deluxe.
This is offered with **absolutely no support** other than what has been
provided here. I have had many requests for this software, but I can not
spare the time for support. Three other people have gotten this to work
with the information below with no problems.

This software was never meant to be used outside of my house, so it is not
polished. It can be seen in use at
<http://www.youtube.com/watch?v=7H98FBQZJ_A>.

The software can be downloaded here:

[736 Windows Emulator.ZIP](736%20Windows%20Emulator.ZIP)

(`emulator setup.doc`, `FT847 Emulator.CAB`, `setup.exe`, `SETUP.LST`)

Here are the brief instructions for making it work. These are included in
the download as well.

You can use three serial ports, or use a free Serial port emulator. I will
show the serial port emulator method here. First, download the emulator at
<http://www.eterlogic.com/Products.VSPE.html>

Open the serial port emulator and create a virtual port. This should be a
port number that does not exist in hardware. This will be what HRD uses to
talk to. In this case below, I created Com Port 7. It is referred to as a
connector, and unlike real serial ports, two devices can connect to it
forming a virtual serial bridge.

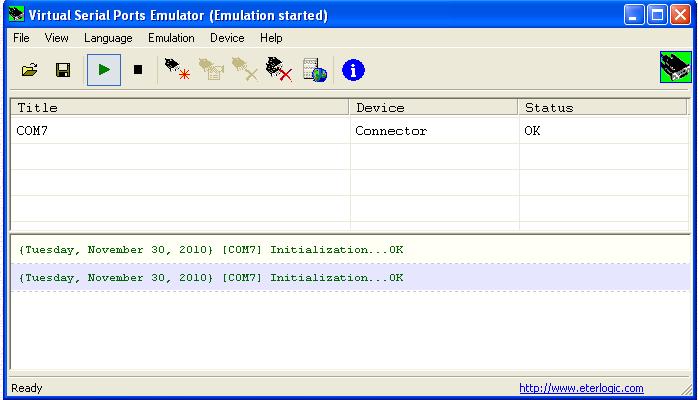
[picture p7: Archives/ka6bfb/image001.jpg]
VSPE connector on COM7


Next, Open up my 847 Emulator and you will get the screen below

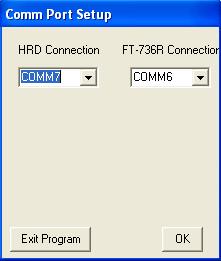
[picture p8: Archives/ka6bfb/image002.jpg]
FT-847 Emulator port setup


HRD com port is the virtual one you just set up.

The 736 port is an actual hardware port that exists on your computer and
used to connect to the 736. See RS-232 interfacing section below hardware
details.

After this is set up, click ok and you will see the following which are the
values of data that are stored from HRD and read back to HRD. These values
are also used to communicate with the 736. The commands are obviously
different, so conversion occurs.

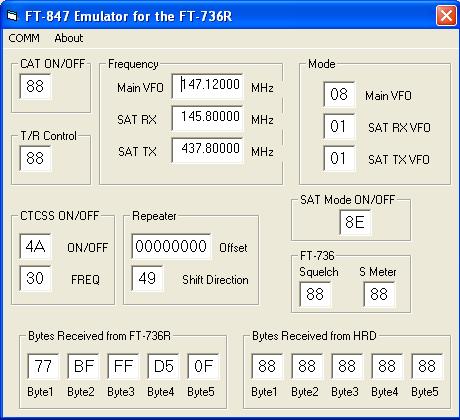
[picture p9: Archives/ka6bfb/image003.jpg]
Emulator status window


Now you are ready to open HRD. My values are shown below. Your serial ports
will probably be different. After all is setup, connect and enjoy the
emulator. After all of this, you can see why I don’t want to release this.

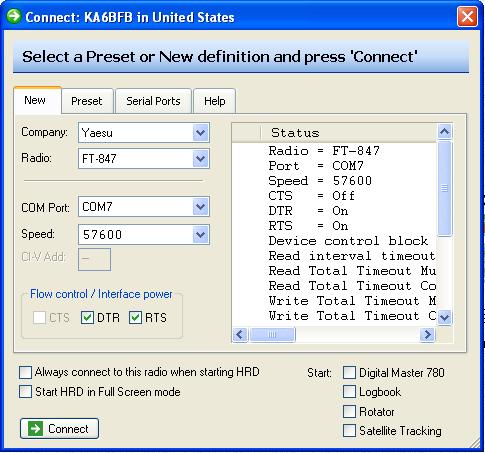
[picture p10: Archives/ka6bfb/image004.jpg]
HRD Connect — FT-847 at 4800


The same HRD Connect window is Fig. 9 in the operating manual:
[`Manual/figures/fig-hrd-connect.png`](../Manual/figures/fig-hrd-connect.png).

## RS-232 Interfacing

There seems to be some confusion about the serial interfacing. Yaesu made
an interface that had a 25 pin serial connector and the appropriate DIN
connector at the other end. These are fairly uncommon these days. The 736
at the DIN connector is expecting TTL levels, so yes inversion and level
shifting is required. Here is a schematic of the circuit I made a while
back. I have two DIN connectors on the output so that I can use it on older
radios like the 736 and newer radios like the FT-817.

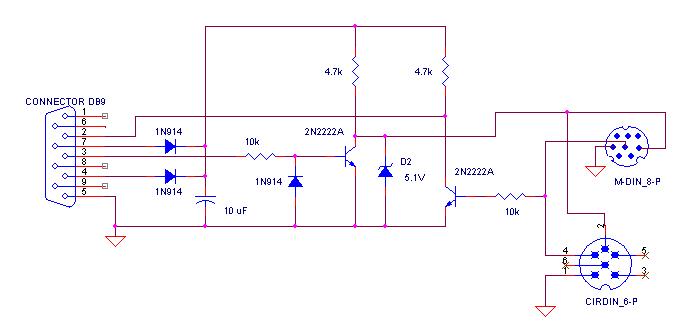
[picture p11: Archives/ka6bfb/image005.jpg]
KA6BFB TTL / RS-232 interface schematic


The N6BIL USB box does **not** need this level shifter: its UART is already
TTL. See [`Hardware.md`](Hardware.md).
The Ham Spot / Arduino CAT pin map (AMSAT) is in
[`Arduino/docs/CONNECTIONS.md`](../Arduino/docs/CONNECTIONS.md).

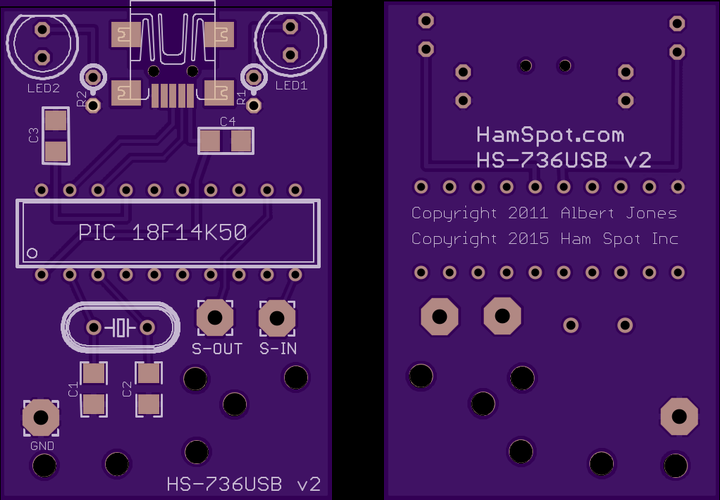
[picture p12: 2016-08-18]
Hardware/Artwork/v2/render.png

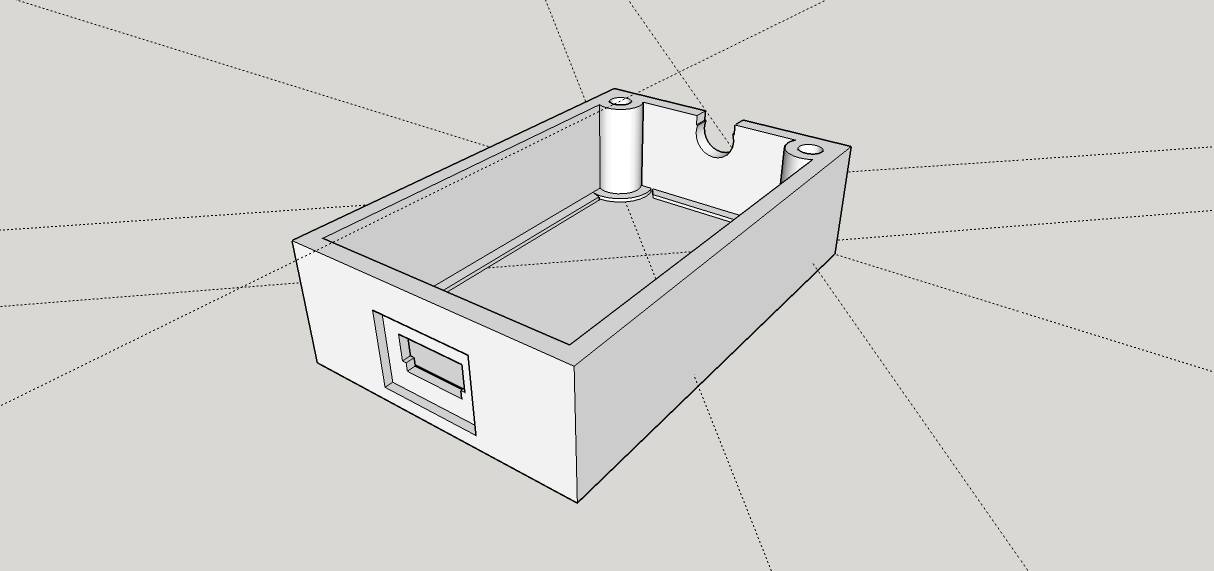
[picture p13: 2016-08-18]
Hardware/Cabinet/v2.1/HS-736RUSB-Enclosure.png

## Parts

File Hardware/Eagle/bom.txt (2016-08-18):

"Part";"Value";"Device";"Package";"Description";"";
"C1";"22pF";"C-USC1206";"C1206";"CAPACITOR, American symbol";"";
"C2";"22pF";"C-USC1206";"C1206";"CAPACITOR, American symbol";"";
"C3";".47µF";"C-USC1206";"C1206";"CAPACITOR, American symbol";"";
"C4";".1µF";"C-USC1206";"C1206";"CAPACITOR, American symbol";"";
"GND";"";"3,17/1,3";"3,17/1,3";"THROUGH-HOLE PAD";"";
"LED1";"";"LED5MM";"LED5MM";"LED";"";
"LED2";"";"LED5MM";"LED5MM";"LED";"";
"MINI-USB";"MINI-USB-UX60-MB-5ST";"MINI-USB-UX60-MB-5ST";"UX60-MB-5ST";"MINI USB Connector";"";
"Q1";"12MHz";"CRYSTALHC49S";"HC49/S";"CRYSTAL";"";
"R1";"82Ω";"R-US_0204/2V";"0204V";"RESISTOR, American symbol";"";
"R2";"82Ω";"R-US_0204/2V";"0204V";"RESISTOR, American symbol";"";
"S-IN";"";"3,17/1,3";"3,17/1,3";"THROUGH-HOLE PAD";"";
"S-OUT";"";"3,17/1,3";"3,17/1,3";"THROUGH-HOLE PAD";"";
"U$1";"14K50_DIP";"14K50_DIP";"14K50_DIP";"14K50 20pin dip";"";

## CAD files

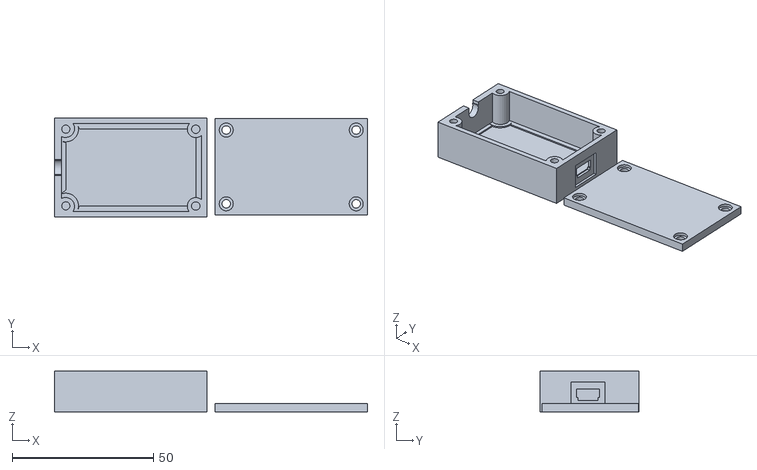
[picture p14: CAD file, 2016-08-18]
Hardware/Cabinet/v2.1/HS-736RUSB-Enclosure.stl
110.9 x 35.1 x 14.5

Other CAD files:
Hardware/Cabinet/v2/hs736usb-laser-v2.dxf
Hardware/Cabinet/v2.1/HS-736RUSB-Enclosure.AMF
Hardware/Cabinet/v2.1/HS-736RUSB-Enclosure.skp

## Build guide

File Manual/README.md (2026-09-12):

# Manuals

Two booklets live here.

| File | What it is |
| --- | --- |
| [`HS-736USB-Manual.pdf`](HS-736USB-Manual.pdf) (and `.doc`) | Original 2014 Ham Spot PIC cabinet booklet (HRD, Windows CDC driver). |
| [`HS-736USB-Operating-Manual.pdf`](HS-736USB-Operating-Manual.pdf) | Yaesu-style operating manual for the CAT box and basic FT-736R use. Covers the PIC cabinet and the Arduino / ATmega328P port. |

Rebuild the operating manual (needs `python3-reportlab`):

```
python3 Manual/build_om.py
```

Figures are in `figures/`. Photographs of the FT-736R (Figs. 1, 3–7) are short excerpts from the Yaesu FT-736R Operating Manual, used here under fair use for identification and instruction. They remain copyright Yaesu Musen Co., Ltd. This is not a Yaesu publication. Fig. 9 is from the original Ham Spot booklet. Figs. 2 and 8 are PIC cabinet artwork. Figs. 2A and 10 are the Arduino Nano carrier (`Hardware/tscircuit/`).

Opcode-level notes: [`Arduino/docs/`](../Arduino/docs/).

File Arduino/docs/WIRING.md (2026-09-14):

# Wiring (ATmega328P Uno / Nano)

Host settings in Hamlib, HRD, SatPC32, WSJT-X: **Yaesu FT-847**, **4800 baud**, **8 data bits**, **no parity**, **2 stop bits**, **no handshake**.

The Arduino USB-serial baud **must** match (this firmware uses 4800 8N2). The original PIC CDC ignored host baud; Uno/Nano cannot.

## CAT jack (FT-736R 6-pin DIN)

Full radio pinouts (front and rear, including known **manual errors**) are in [`CONNECTIONS.md`](CONNECTIONS.md).

AMSAT-corrected CAT map. Some Yaesu manuals number these pins wrong.

| DIN pin | Signal | Arduino |
| --- | --- | --- |
| 1 | GND | GND |
| 2 | Serial In (S.IN) — **into the radio** | **D9** (AltSoftSerial TX) |
| 3 | Busy | **D10** (LOW = squelch open) |
| 4 | Serial Out (S.OUT) — **out of the radio** | **D8** (AltSoftSerial RX) |
| 5 | NC | no connect |
| 6 | +13.8 V | **do not connect** |

Rear of **male** plug (pins toward you). Numbers are **not** sequential:

```
             3           1
                   6
             5           4
                   2

        1 GND     2 S.IN (adapter TX)     3 BUSY
        4 S.OUT (adapter RX)   5 NC    6 +13.8 V (leave open)
```

```
PC USB -- 328 USART0 (4800 8N2)     host sees an FT-847
D9 TX  ---------------->  CAT pin 2  S.IN     TTL, idle high
D8 RX  <----------------  CAT pin 4  S.OUT
GND    -----------------  CAT pin 1
D13        activity LED
         (no wire to pin 6)
```

Levels match the original HS-736USB (PIC UART TTL, no MAX232). If a particular radio only clocks inverted/open-collector CAT, add an NPN inverter on D9; that is not the default.

Power the Arduino from USB. Do not feed CAT pin 6 into the 5 V pin.

## Accessory GPIO (not FT-847 CAT)

PTT out, band decode, and S-meter PWM. See `CONNECTIONS.md` for the radio’s own STBY DIN (prefer that for band-keyed linears if you can).

| Pin | Direction | Function |
| --- | --- | --- |
| **D2** | out | PTT MOSFET gate. HIGH when **CAT PTT or RCA sense** is keyed |
| **D3** | PWM | S-meter (0–255), Timer2 |
| **D4** | out | One-hot 50 MHz |
| **D5** | out | One-hot 144 MHz |
| **D6** | out | One-hot 220 MHz |
| **D7** | out | One-hot 430 MHz |
| **D10** | in | CAT pin 3 **BUSY**. INPUT_PULLUP; **LOW = squelch open / carrier**. Measure 5 V before wiring. |
| **D11** | in | MCP **INT** (encoder A/B). Unused if `HS736_MCP` is 0. |
| **D12** | in | Encoder **SW** when using MCP23008. Free on MCP23017. |
| **D13** | out | Dialect LED: HIGH = FT-847, LOW = FT-736 |
| **A0** | in | Optional PTT **sense** (active LOW) |
| **A1** | in (PCINT) | Protocol: **HIGH = FT-847**, **LOW = FT-736 native**. Debounced 50 ms. Two stable flips in 1 s restore jumper-follow if CAT had forced a dialect. See `docs/PROTOCOLS.md` |
| **A4, A5** | I2C | SDA / SCL to MCP23008 or MCP23017. **A2, A3** free. |

### Optional expander (`HS736_MCP`)

A 4-bit HD44780 still needs **six** lines (RS, E, D4–D7; RW to GND). That already fills most of an 8-bit MCP23008, so the 08 option keeps LCD + encoder A/B on the chip and puts the shaft switch on **D12**.

In `firmware/hs736_features.h`:

| `HS736_MCP` | Chip | LCD | Encoder A/B | Encoder SW |
| --- | --- | --- | --- | --- |
| **17** (default) | MCP23017 0x20 | GPA0–5 | GPB0, GPB1 | GPB2 |
| **8** | MCP23008 0x20 | GP0–5 | GP6, GP7 | Nano D12 |
| **0** | none | off | off | off |

```
-DHS736_MCP=0
-DHS736_MCP=8
-DHS736_USE_MCP23017=0   # same as MCP=0
-DHS736_USE_MCP23008=1   # same as MCP=8
```

PTT, band D4–D7, PWM, BUSY, dialect LED, A1 jumper, and CAT are unchanged.

| MCP pin | 23017 | 23008 |
| --- | --- | --- |
| HD44780 D4–D7 | GPA0–GPA3 | GP0–GP3 |
| RS / E | GPA4 / GPA5 | GP4 / GP5 |
| encoder A / B | GPB0 / GPB1 | GP6 / GP7 |
| encoder SW | GPB2 | Nano D12 |
| INT | INTA → D11 | INT → D11 |
| address | A0–A2 GND | A0–A2 GND |

Encoder: one detent = one step. Default **1 kHz** in AM/FM-N/FM-W, **100 Hz** otherwise. Short press: cursor on the displayed freq digits. Long press (~600 ms): AM → FM-N → FM-W → LSB → USB → CW-N → CW-W.

No 2-bit band outputs. 1240 MHz is on the LCD and in CAT (host shows 240 MHz), not a one-hot pin. Satellite: one-hot **both** RX and TX among 50/144/220/430.

16×2 Hitachi (when MCP is enabled): line 1 frequency + mode + 847/736; line 2 last 5 radio bytes (hex) + 5-cell S-meter bar. Host `E7` returns the last polled 736 `F7` mapped to 847 RX status (bits 0–4 dots, bit7 squelch from BUSY).

### PTT MOSFET (output)

```
  D2 -- 100Ω -- MOSFET gate   (2N7000 small; IRLZ44 / logic-level for bigger coils)
                 10k to GND
  MOSFET source -- Arduino GND -- radio GND
  MOSFET drain  -- amp PTT / relay (coil other side to +12 V, diode across coil)
```

Output is HIGH for TX. That turns the N-MOSFET on and **grounds** the amp PTT line (same sense as the 736 STBY jack).

CAT `08`/`88` **or** the sense input keys this pin. Mic / MOX / footswitch therefore keys the amp even when CAT is off.

### PTT RCA sense (optional input)

The 736 PTT RCA is **8 V** open, ground-to-TX. **Do not** wire 8 V straight to A0.

Y-cable the radio RCA: one leg still to a footswitch if you use one; the other to the Arduino:

```
  RCA center -- 22 kΩ --+-- A0
                        +-- 5.1 V zener to GND   (cathode at A0)
  RCA sleeve ----------- GND

  Firmware: INPUT_PULLUP, TX = pin LOW.
  Unplugged = RX (pull-up).
```

Pass-through: `PTT_out = CAT_PTT OR (A0 == LOW)`.

Front-panel MOX and the mic PTT close the same RCA line, so this input sees them. CAT PTT keys the radio over serial, not the RCA; the MOSFET still follows CAT PTT.

### S-meter PWM

Queries the 736 with CAT `F7` (not the fake 847 `F7` on USB). **3 s** when idle; **3× command-send time** (~633 ms) when keyed in the last 5 minutes or PWM ≥ 84 (33%). D3 PWM **slews** from the last sample to the new one over that same window so the needle does not jump. Host CAT still wins the UART.

## Radio setup

From the original HS-736USB README: memory channels are not supported. Set the radio to **VFO**, and satellite mode to **VFO**, before enabling CAT. CAT ON locks the front panel. 1240 MHz is shown to the PC as 240 MHz.

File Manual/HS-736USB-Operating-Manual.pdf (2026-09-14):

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
# OPERATING MANUAL

# HS-736USB

## FT-736R CAT INTERFACE

Arduino / ATmega328P edition

### HAM SPOT INC

http://hamspot.com/
FT-736R to computer CAT -- USB

Not a Yaesu publication. See notice inside.

HS-736USB OPERATING MANUAL | FT-736R CAT INTERFACE
- 1 -

### NOTICE

This booklet is the operating manual for the HS-736USB computer-aided transceiver interface: a small USB box that lets modern amateur-radio software talk to a Yaesu FT-736R as if the radio were an FT-847. It also covers the few front- and rear-panel operations you need on the 736 itself so that CAT control will work.

It is not a Yaesu publication and does not replace the FT-736R Operating Manual or Technical Supplement. FT-736R, FT-847 and YAESU are trademarks of Yaesu Musen Co., Ltd. Photographs of the transceiver in this booklet are short excerpts from the original Yaesu FT-736R Operating Manual, reproduced here under fair use for identification and instruction only. Those images remain copyright Yaesu Musen.

The HS-736USB firmware (PIC original by N6BIL, Arduino port in this repository) is licensed under the GNU General Public License version 3. Hardware CAD, this booklet, and the remainder of the Ham Spot tree follow the same license unless a file says otherwise.

Credits: Dave KA6BFB (software proof of concept), Chuck N6BIL (PIC hardware translator, GPL), Ham Spot Inc (HS-736USB product), and the Arduino / ATmega328P port in Arduino/.

### CONTENTS

Section 1. General Description
Section 2. The FT-736R at a Glance
Section 3. Installation of the Interface
Section 4. Basic Operation of the Radio with CAT Section 5. Computer Software
Section 6. FT-847 and FT-736R Dialects
Section 7. Accessory GPIO (Arduino / Nano carrier) Section 8. In Case of Difficulty
Appendix A. CAT Pin Map (use this)
Appendix B. Specifications of the Interface

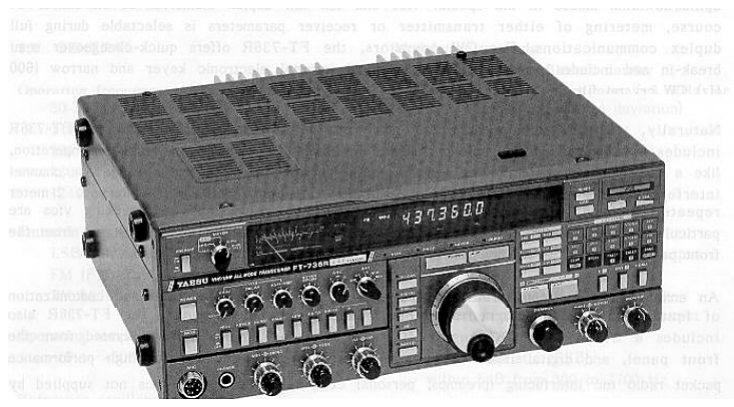
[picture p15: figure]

- 2 -

### Section 1. GENERAL DESCRIPTION

Fig. 1 Yaesu FT-736R VHF/UHF multimode base (excerpt from the Yaesu Operating Manual).

### 1.1 The HS-736USB Interface

The FT-736R remains a first-class satellite and VHF/UHF station. Its CAT (Computer Aided Transceiver) jack is TTL serial at 4800 bit/s, 8 data bits, no parity, 2 stop bits. Many current programs — Ham Radio Deluxe in particular — never learned the 736 dialect. They did learn the later FT-847.

The HS-736USB sits between the computer and the radio. On USB it presents an FT-847 CAT port. On the DIN cable it speaks native FT-736R CAT, including the 23 cm mapping the 847 never had. Features the 736 does not have are ignored. Memory channels are not supported: put the radio on a VFO, and satellite mode on VFO, before you turn CAT on.

Two hardware generations exist. The original Ham Spot box is a PIC18F14K50 in a Hammond enclosure (see Firmware/ and Hardware/Eagle/). The Arduino / ATmega328P port in Arduino/ is a drop-in replacement of that translator. The Nano carrier in Hardware/tscircuit/ is the board that generation sits on: the Nano plugs in; CAT, PTT MOSFET, RCA sense, dialect jumper, LCD, band and S-meter PWM are on the carrier. User operation of CAT is the same on PIC and Arduino.

Fig. 2 Original HS-736USB printed circuit (v2 artwork, PIC18F14K50). USB Mini-B to the computer; S-IN / S-OUT / GND to the radio CAT jack.

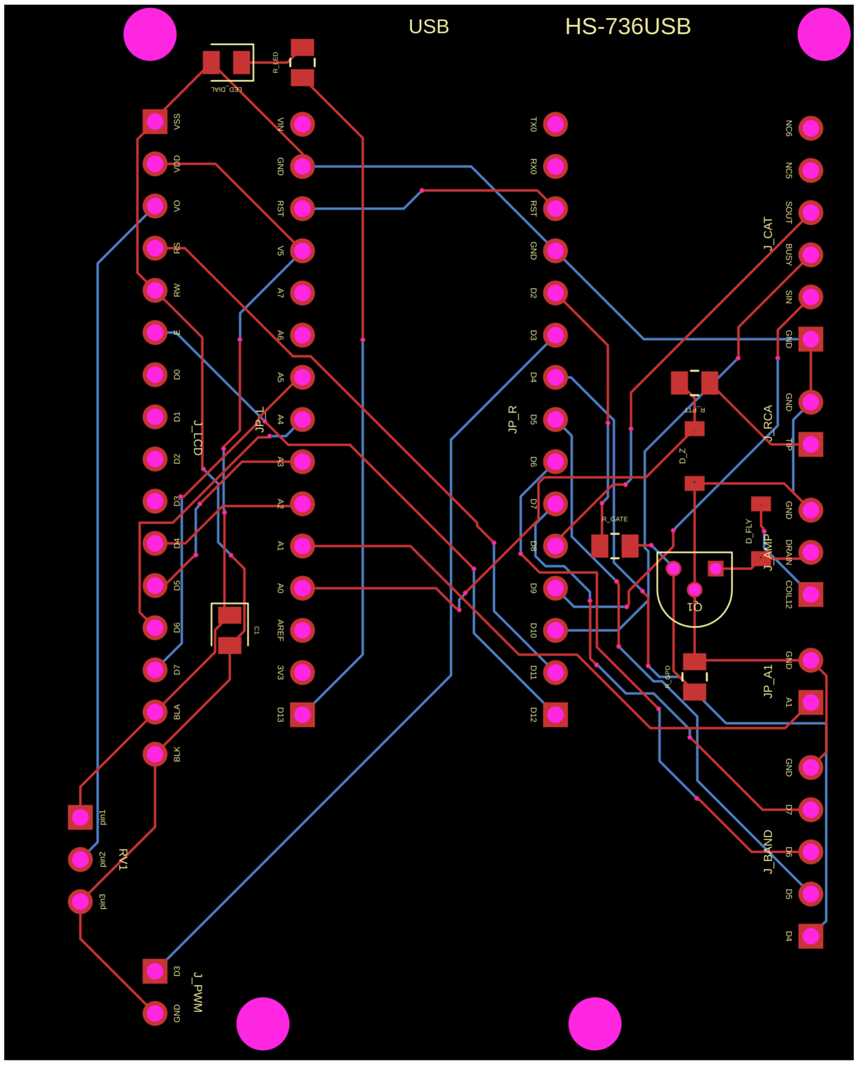
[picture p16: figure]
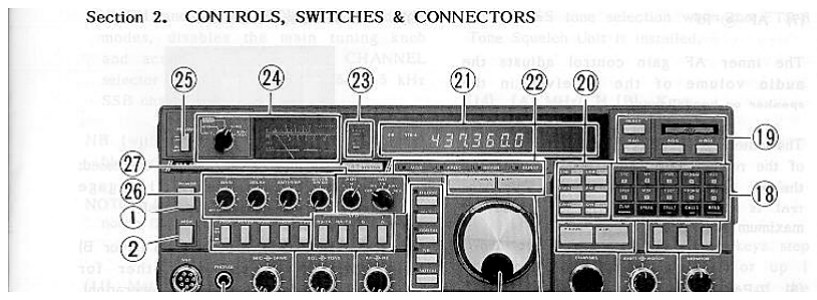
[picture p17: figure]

- 3 -

Fig. 2A Arduino Nano carrier (tscircuit). The Nano plugs into JP_L / JP_R (USB at the top). J_CAT is the 6-pin AMSAT CAT jack; pin 6 is not connected. Power is Nano USB 5 V. Red = top copper, blue = bottom.

### 1.2 What You Need

- An FT-736R with CAT enabled in the usual way (see §4).
- The HS-736USB (PIC cabinet or Arduino Nano carrier), powered from USB.
- A 6-pin DIN 240° (270° key) cable, wired to the AMSAT map in Appendix A — not blindly from a photocopied Yaesu pin-number drawing.
- Station software that can speak Yaesu FT-847 CAT at 4800 8N2 (Ham Radio Deluxe, Hamlib -m 1001, SatPC32, WSJT-X, …), or native FT-736 CAT (-m 1010) if you put the Arduino in 736 dialect.

### Section 2. THE FT-736R AT A GLANCE

This section is a short tour of the controls you will actually touch when the interface is in the station. It is not a substitute for Section 2 of the Yaesu Operating Manual.

### 2.1 Front Panel

Fig. 3 Front panel, numbered as in the Yaesu Operating Manual (excerpt).

(1) POWER
Turns the transceiver on and off. Apply AC (or 13.8 V DC) and leave POWER on before you plug the interface into the computer; CAT ON from the PC will then lock the front panel.
(2) MOX
Manual transmit. With CAT running, Ham Radio Deluxe’s on-screen PTT can drop the radio out of satellite mode — a long-standing HRD bug. The reliable workaround is to transmit with MOX, the microphone PTT, or a footswitch on the rear RCA, not with the program’s PTT button. See §5.3.
(3) MIC jack

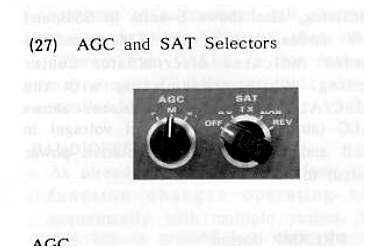
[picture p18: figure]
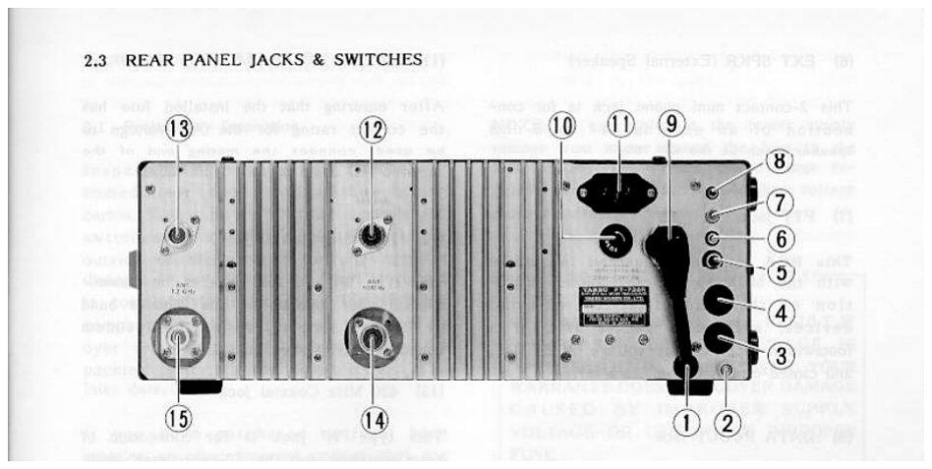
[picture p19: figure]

- 4 -

8-pin locking connector for the stock MH-1B8 (or MD-1B8 desk mic). Pin 2 is earth on the 736, not +5 V. An unmodified MH-31B8 does not drop in.

(11) Main Tuning Knob · (21) Display
Once CAT is on, the front panel is locked and the computer owns frequency and mode. Set the radio to a VFO (not a memory channel) before CAT ON. 1240 MHz is shown to FT-847 software as 240 MHz (the 847 has no 4 MHz digit).

Fig. 4 AGC and SAT selectors (excerpt from the Yaesu Operating Manual).

(27) SAT selector
Full-duplex satellite operation. OFF is simplex. RX / TX display and tune one side while the other is fixed. NOR tracks both VFOs the same way; REV tracks them in opposite directions (the usual amateur-satellite inverting transponder). Leave this on a VFO-related SAT position, not a memory, before enabling CAT. The computer then turns full duplex on and off with the 847 4E / 8E (translated to 736 0E / 8E).

### 2.2 Rear Panel

Fig. 5 Rear panel jacks (excerpt from the Yaesu Operating Manual). CAT is item (3), the 6-pin DIN above the KEY jack.

Typical layout, viewed from behind: DC pigtail from the internal switcher and the white 13.8 V inlet; ground screw; CAT 6-pin DIN 240°; STBY 5-pin DIN (amplifier ground-on-TX); KEY; EXT SPKR; PTT RCA; DATA IN/OUT; fuse; AC inlet; antenna jacks (N on 430, SO-239 on 144; optional modules below).

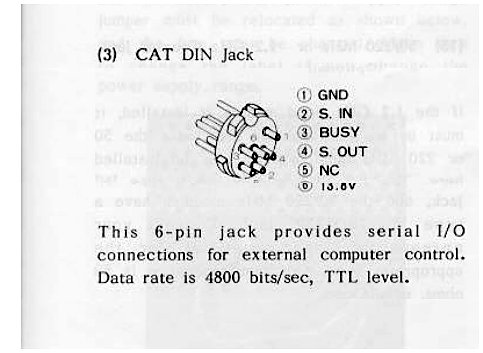
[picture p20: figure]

- 5 -

Fig. 6 CAT DIN as printed in the Yaesu Operating Manual (4800 bit/s, TTL). Use the AMSAT pin map in Appendix A — some printings number the shell differently.

MANUAL ERRORS

Do not trust a random photocopy of the operating manual for CAT or DATA pin numbers. Some printings number DIN pins with a Japanese / Yaesu order instead of IEC 60130, and some print the DATA jack tip/ring backwards. Identify CAT pins by the keyway plus the AMSAT map (Appendix A). On the radio, S.IN is data into the 736 (adapter TX); S.OUT is data out of the 736 (adapter RX).

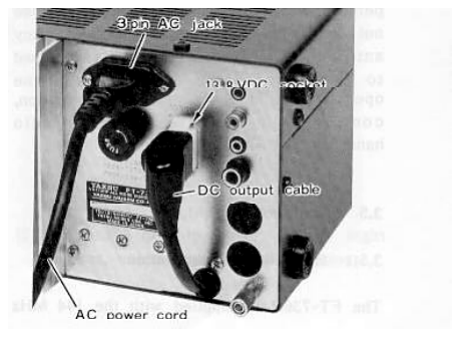
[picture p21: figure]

- 6 -

### Section 3. INSTALLATION OF THE INTERFACE

### 3.1 Powering the Radio

Fig. 7 AC inlet, DC pigtail and 13.8 V socket (excerpt from the Yaesu Operating Manual).

Before connecting mains, read the voltage label on the rear panel (100 / 117 / 220 / 234 V versions exist) and confirm the fuse matches that range (4 A on the low range, 2 A on the high range). For AC operation plug the internal-supply pigtail into the white 13.8 V inlet, then the AC cord. An external 13.8 V supply must be able to deliver 8 A continuous.

- ! ! ! ! ! ! CAUTION ! ! ! ! ! ! -

PERMANENT DAMAGE WILL RESULT IF IMPROPER SUPPLY VOLTAGE IS APPLIED TO THE TRANSCEIVER. YOUR WARRANTY DOES NOT COVER DAMAGE CAUSED BY IMPROPER SUPPLY VOLTAGE OR USE OF AN IMPROPER FUSE. DO NOT CONNECT THE MAINS CORD UNTIL ALL OTHER INTERCONNECTIONS HAVE BEEN MADE.

### 3.2 Connecting the HS-736USB

Power the interface from USB only. Wire a 6-pin DIN plug as follows (rear of the male plug, pins toward you; numbers are not sequential around the shell):

DIN pin | Radio name | Interface
1 | GND | GND
2 | S.IN (serial data in) | TX to the radio (Arduino D9)
3 | BUSY | PIC: no connect. Nano J_CAT: D10
4 | S.OUT (serial data out) | RX from the radio (Arduino D8)
5 | NC | no connect
6 | +13.8 V | do not connect

PIC cabinet: the silkscreen already reads S-IN / S-OUT / GND; those pads go to pins 2, 4 and 1. Nano carrier: plug the 6-pin DIN into J_CAT (GND, SIN, BUSY, SOUT, NC, NC). Pin 6 is not connected. Arduino D9 is AltSoftSerial TX, D8 is RX (Timer 1). Levels are TTL idle-high, same as the original HS-736USB. Do not insert a MAX232 unless your particular radio only clocks inverted CAT.

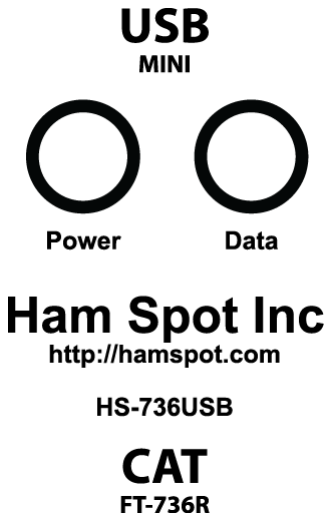
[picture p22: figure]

- 7 -
- ! ! ! ! ! ! CAUTION ! ! ! ! ! ! -

DO NOT FEED CAT PIN 6 (+13.8 V) INTO THE ARDUINO 5 V PIN OR THE PIC VDD RAIL. POWER THE INTERFACE FROM USB. PIN 6 IS A RADIO SUPPLY OUTPUT, NOT A SIGNAL.

Fig. 8 Original HS-736USB cabinet legend (USB Mini-B, CAT to the FT-736R).

### 3.3 The Computer Port

Arduino / ATmega328P. The host USB-serial baud must be 4800 8N2 with no handshake. The original PIC CDC ignored the host baud; an Uno or Nano cannot. A genuine Uno (ATmega16U2) enumerates as Arduino USB serial; many Nano clones use a CH340. Install the matching driver if the operating system does not already have one. No Microchip mchpcdc.inf is required.

Original PIC HS-736USB. Windows enumerates the box as “CDC RS-232 Emulation Demo”. The 2014 booklet walked through the Found New Hardware Wizard and Microchip’s INF. That procedure applies only to the PIC cabinet, not to the Arduino port.

NOTE

Host settings in Hamlib, HRD, SatPC32 and WSJT-X: radio model Yaesu FT-847, 4800 baud, 8 data bits, no parity, 2 stop bits, no handshake. Default Arduino dialect is FT-847 (pin A1 open / HIGH). Ground A1, or send the CAT override in §6, for native FT-736.

### Section 4. BASIC OPERATION OF THE RADIO WITH CAT

### 4.1 Before You Enable CAT

1. POWER the radio. Confirm receive audio and that the correct antenna jack is in use for the band you intend (144 SO-239, 430 type N, optional modules on the lower pair).
2. Select a VFO with the VFO / MR keys. Do not leave the radio on a memory channel. The interface does not handle memories.
3. If you will run satellite, set the SAT selector to a VFO position (RX, TX, NOR or REV) — not a duplex memory. Simplex: SAT to OFF.
4. Plug in the CAT cable and the USB cable. The activity LED (Arduino D13, or the PIC cabinet LED) will blink when bytes move.

### 4.2 CAT ON and the Front Panel Lock

When the computer sends CAT ON (00), the 736 locks its front panel. In FT-847 dialect the adapter also forces 145.000 MHz FM onto the radio as the 847 CAT-ON extra; your logging program then writes the real frequency. CAT OFF (80) unlocks the panel. Do not fight the lock with the D LOCK button — turn CAT off from the PC if you need the knobs.

- 8 -

### 4.3 Simplex

Set band and mode from the program (or, before CAT ON, from the MODE buttons: LSB, USB, FM-N, FM, CW-N, CW). Tune from the program. PTT is CAT 08 on / 88 off, or MOX / mic / rear RCA. Repeater shift and CTCSS are translated; DCS from 847-style commands is dropped. The 736 simplex opcode is 89 — 88 is PTT off, despite some old 736 charts.

### 4.4 Satellite (full duplex)

With the adapter in FT-847 dialect (the usual HRD / SatPC32 / Hamlib 1001 case), the PC sends 847 satellite opcodes; the box rewrites them to 736:

What you want | PC (FT-847) | Radio (FT-736R)
Full duplex on | 4E | 0E
Sat RX frequency | 11 | 1E
Sat TX frequency | 21 | 2E
Sat RX / TX mode | 17 / 27 | same opcodes
Full duplex off | 8E | 8E then restore main VFO
Tone | 0B | FA

If the PC is speaking native 736 while the adapter is in 847 mode, those 736 sat opcodes are dropped with no error. Simplex will still appear to work. That is the usual “SatPC32 won’t go duplex” failure — the program is set to FT-736 instead of FT-847. See §6.

4.5 23 cm
The FT-847 has no 4 MHz digit, so 1240–1299.99999 MHz is shown to the PC as 240–299.99999 MHz. The adapter adds 0xA0 to the first frequency BCD byte when it writes the radio. Tune 23 cm in the program as 240 MHz, not 1240 MHz.

### 4.6 After the QSO

Send CAT OFF before you unplug USB or power the radio down. If the panel stays locked, cycle POWER on the 736; that clears CAT as surely as 80.

### Section 5. COMPUTER SOFTWARE

### 5.1 Ham Radio Deluxe

On the Connect window, open the Serial Ports tab and note which COM (or /dev/ttyUSBn, /dev/ttyACM0) the interface received. Create a new connection: Company Yaesu, Radio FT-847, that port, speed 4800, CTS/DTR/RTS off.

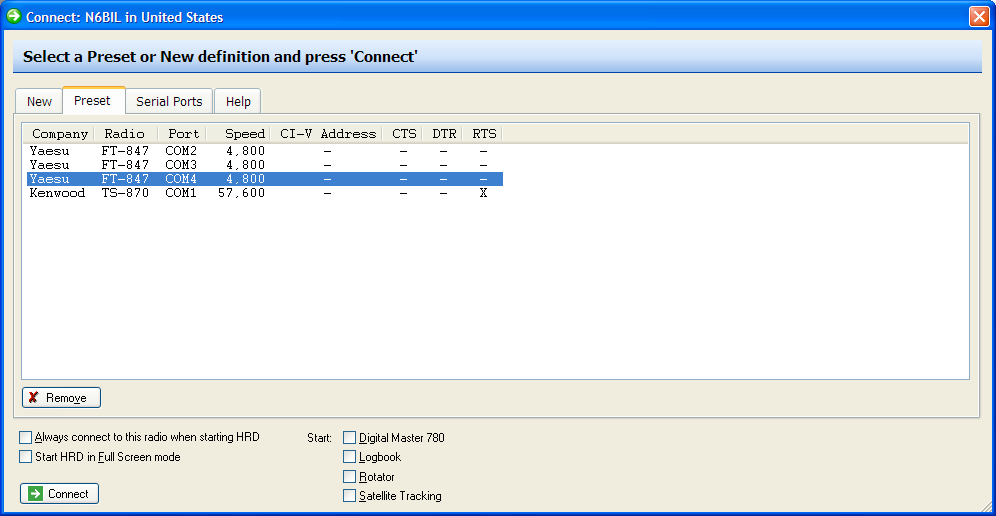
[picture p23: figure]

- 9 -

Fig. 9 Ham Radio Deluxe Connect window — Yaesu FT-847 at 4,800 (from the original HS-736USB booklet).

### 5.2 Hamlib, SatPC32, WSJT-X

Hamlib: rigctl -m 1001 -r PORT -s 4800 for 847 dialect (default). Native 736 is -m 1010 and requires the adapter in 736 dialect (§6). SatPC32 and WSJT-X: pick FT-847, 4800 8N2, no flow control. Do not raise the radio CAT baud — the 736 stays at 4800; the adapter does not change it.

### 5.3 Known Issues with HRD

SAT PTT. If you press SAT on the radio, HRD will show SAT. If you then use HRD’s software PTT, HRD may drop out of SAT mode while the 736 is still in SAT. Workaround: transmit with the radio MOX button, the mic PTT, or a footswitch. Do not use the on-screen PTT while in satellite mode.

Two-band satellite swap. Changing TX/RX bands in SAT via HRD is awkward on a two-band 736. A three- or four-band radio is easier. Example: TX on 2 m and RX on 70 cm — park TX on 6 m / 220 / 1200 briefly, move RX to 2 m, then put TX on 70 cm.

### Section 6. FT-847 AND FT-736R DIALECTS

The Arduino port (not the original PIC) can speak either language on USB. The radio is always driven as a 736. Pin A1 is an input with pull-up:

A1 | USB dialect | Use with
HIGH (open) | FT-847 (default) | Hamlib 1001, HRD, SatPC32 as FT-847
LOW (jumper to GND) | FT-736R native | Hamlib 1010, programs that speak 736

A pin-change interrupt switches immediately and drops any half-finished 5-byte USB frame so the two dialects are never mixed. Frequency, PTT and sat flags in RAM stay put — you may flip the jumper mid-QSO without sending CAT OFF. Bounce is debounced 50 ms.

### 6.1 CAT Override

A non-Yaesu 5-byte block can ignore A1 for a while. It is accepted in both dialects:

A5 73 36 <sel> FC

<sel> | Source | Effect
00 | Jumper | Follow A1 again
01 | Force 847 | 847 even if A1 is low

- 10 -
<sel> | Source | Effect
02 | Force 736 | 736 even if A1 is high
FF | Cycle | jumper -> 847 -> 736 -> jumper

Two stable jumper flips inside one second (wiggle the pin) cancel a CAT force and return to jumper-follow. Nothing in this block is sent to the radio.

### 6.2 If You Speak the Wrong Dialect

The adapter will not NAK. Unknown opcodes are dropped with no USB error. Overlap is large enough that simplex can look fine while satellite is silently dead.

736 software into an 847-mode adapter: duplex ON 0E, sat frequencies 1E/2E and tone FA never reach the radio. 736 CTCSS-on {00,00,00,00,0A} is misread as CAT ON and re-locks the panel.

847 software into a 736-mode adapter: 4E, 11, 21, 0B are locked out. HRD/SatPC32 satellite will not work until A1 is high again. Native 736 sat does work in this mode, and E7/F7 are queried from the radio instead of a dummy 847 cache.

### Section 7. ACCESSORY GPIO (ARDUINO / NANO CARRIER)

These pins are extras on the Uno/Nano port. They are not FT-847 CAT. On the Nano carrier they are headers next to the socket (Fig. 2A / Fig. 10). Prefer the radio’s own STBY 5-pin DIN for band-keyed linears if you can.

Pin | Dir. | Function
D2 | out | PTT MOSFET gate. HIGH when CAT PTT or RCA sense is keyed
D3 | PWM | S-meter (0–255), Timer 2
D4–D7 | out | One-hot 50 / 144 / 220 / 430 MHz
D10 | in | CAT BUSY (LOW = squelch open)
D11 | in | MCP INT (encoder); unused if expander off
D12 | in | Encoder SW on MCP23008; free on MCP23017
A4, A5 | I2C | SDA/SCL to MCP23008 or MCP23017
A0 | in | Optional PTT sense (active LOW)
A1 | in | Dialect: HIGH = 847, LOW = 736
D8 / D9 | UART | CAT RX / TX (AltSoftSerial)
D13 | out | Dialect LED (HIGH = 847)

No 2-bit band outputs. 1240 MHz is shown on the LCD (host CAT as 240 MHz). In satellite, one-hot drives both RX and TX among 50/144/220/430.

Carrier jack | Pins | Goes to
J_CAT | GND SIN BUSY SOUT NC NC | FT-736R CAT DIN (pin 6 open)
J_AMP | COIL12 DRAIN GND | amp PTT MOSFET drain / coil +12
J_RCA | TIP GND | radio PTT RCA sense (22 k + zener)
JP_A1 | A1 GND | open = 847 dialect; jumper = 736
J_BAND | D4 D5 D6 D7 GND | one-hot 50 / 144 / 220 / 430

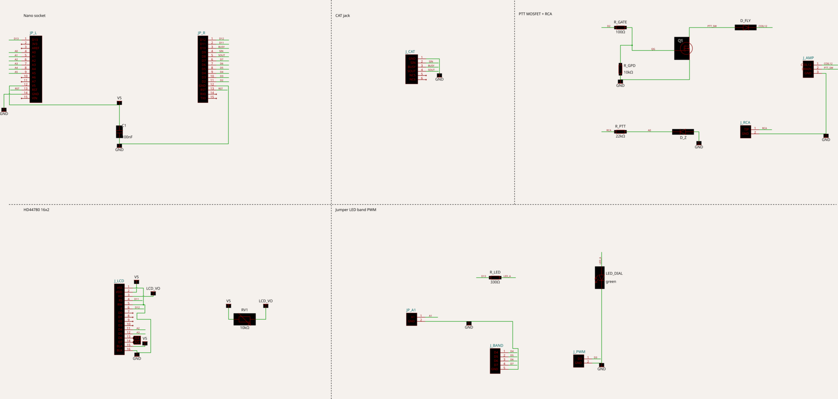
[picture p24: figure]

- 11 -
Carrier jack | Pins | Goes to
J_PWM | D3 GND | S-meter PWM
J_LCD | 16-pin HD44780 | parallel from MCP23017; RV1 contrast; no backpack
J_ENC | 5 V GND A B SW | KY-040; short press digit, long press mode

Fig. 10 Nano carrier schematic (same netlist as Fig. 2A). Nano socket, CAT jack, PTT MOSFET + RCA, HD44780, dialect jumper / LED / band / PWM.

### 7.1 PTT MOSFET

D2 -- 100 ohm -- MOSFET gate, 10 kohm to ground. Source to Arduino GND (common with radio GND). Drain to the amplifier PTT / relay (other side of the coil to +12 V, diode across the coil). A 2N7000 is enough for a small relay; use a logic-level power MOSFET for bigger coils. Output HIGH = TX = ground the amp PTT line, same sense as the 736 STBY jack. CAT 08/88 or the sense input keys this pin, so mic / MOX / footswitch keys the amp even when CAT PTT is idle.

### 7.2 Rear RCA PTT Sense (optional)

The 736 PTT RCA is 8 V open, ground-to-TX, 8 mA closed. It is in parallel with MOX and the mic PTT. 8 V will destroy a 328 pin. Y-cable the RCA: one leg still to a footswitch if you use one; the other through 22 kohm to A0, with a 5.1 V zener to GND (cathode at A0). Firmware: INPUT_PULLUP, TX = pin LOW. Unplugged = RX.

- ! ! ! ! ! ! CAUTION ! ! ! ! ! ! -

DO NOT WIRE THE 8 V PTT RCA DIRECTLY TO A0. USE THE 22 kohm SERIES RESISTOR AND 5.1 V ZENER. CAT PTT STILL KEYS THE RADIO OVER SERIAL; THE MOSFET FOLLOWS CAT PTT OR THIS SENSE LINE.

### 7.3 S-Meter PWM

The adapter queries the 736 with CAT F7 (the real radio command, not the dummy 847 F7 on USB). Polling is every 3 s when idle, and about 633 ms (three times the CAT send time) when you have keyed in the last five minutes or the meter is above about S3. D3 PWM slews from the last sample to the new one across that window so an analog meter does not jump. Host CAT still wins the UART if a command arrives mid-poll.

### Section 8. IN CASE OF DIFFICULTY

- 12 -
Symptom | Likely cause | What to do
No COM port | Driver, cable, or board | PIC: Microchip CDC INF. Arduino: 16U2 or CH340 driver. Try another USB cable that actually has data wires.
Port exists, radio ignores CAT | Baud, DIN map, or CAT OFF | Host must be 4800 8N2 on Arduino. Confirm pin 2 = adapter TX, pin 4 = adapter RX, pin 1 = GND. Send CAT ON. Do not use pin 6.
Simplex works, sat does not | Wrong dialect | A1 HIGH and software = FT-847. Native 736 opcodes are dropped in 847 mode.
Panel locked, knobs dead | CAT is on | CAT OFF from the PC, or POWER-cycle the 736.
HRD drops SAT on PTT | HRD bug | Use MOX, mic PTT, or footswitch. Do not use HRD’s PTT in SAT.
23 cm is 1 GHz off | 847 digit limit | Tune 240 MHz in the program for 1240 MHz on the air.
Arduino dies when RCA is plugged in | 8 V on A0 | Add the 22 kohm + zener. Do not continue on a damaged 328.
S-meter PWM stuck | Poll lost the UART | Host CAT has priority. Idle the program; the next F7 should move D3.

- 13 -

### Appendix A. CAT PIN MAP (USE THIS)

Wire from the drawing below (Fig. 6, repeated) and this table. AMSAT W6SHP: some FT-736R manuals and an old Yaesu application note numbered the CAT shell sequentially; the pins are not. Identify the keyway, then the numbered pins on the plug drawing.

Fig. 6 (repeated). CAT 6-pin DIN from the Yaesu Operating Manual. Pin functions 1–6 match AMSAT; do not recount around the shell.

Pin | Radio name | HS-736USB / Arduino
1 | GND | GND
2 | S.IN (serial data in) | TX to the radio (D9)
3 | BUSY | PIC: no connect. Nano: D10 (J_CAT)
4 | S.OUT (serial data out) | RX from the radio (D8)
5 | NC | no connect
6 | +13.8 V | do not connect

Looking into the radio’s CAT socket (holes), the pattern is mirrored left-right. DATA IN/OUT on the 3.5 mm jack is a separate story: tip = received data from the radio, ring = transmit data to the radio, sleeve = GND. Some manuals swap tip and ring in the drawing. Full front- and rear-panel pinouts: Arduino/docs/CONNECTIONS.md.

- 14 -

Appendix B. SPECIFICATIONS OF THE INTERFACE

Item | PIC HS-736USB | Arduino Nano carrier
Host CAT | FT-847, 4800 8N2 (CDC ignores baud) | FT-847 or FT-736, baud must be 4800 8N2
Radio CAT | 736, 4800 8N2 TTL, 50 ms inter-byte | same, on J_CAT (pin 6 open)
23 cm to PC | shown as 240 MHz | same
Memories | not supported; VFO only | same
Dialect switch | 847 only | JP_A1 (A1–GND), IRQ, CAT A5 73 36 sel FC
PTT accessory | — | J_AMP MOSFET; optional J_RCA sense
Band decode | — | J_BAND one-hot D4–D7 (50/144/220/430)
S-meter | — | J_PWM D3, slewed, radio F7 poll
Display | — | J_LCD 16×2 HD44780, RV1 contrast
MCU board | PIC18F14K50 on the PCB | Arduino Nano in JP_L / JP_R
CAD | Hardware/Eagle | Hardware/tscircuit
Firmware | Firmware/Source (GPL-3) | Arduino/firmware (GPL-3)

Opcode notes: Arduino/docs/. Original PIC booklet: Manual/HS-736USB-Manual.pdf. Figs. 1 and 3–7: Yaesu FT-736R Operating Manual (fair use). Fig. 9: HS-736USB booklet. Figs. 2 and 8: Ham Spot. Figs. 2A and 10: Nano carrier (Hardware/tscircuit).

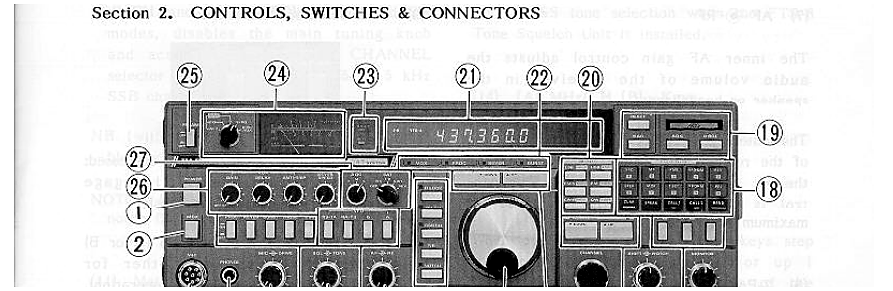
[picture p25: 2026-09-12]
Manual/figures/fig-front.png

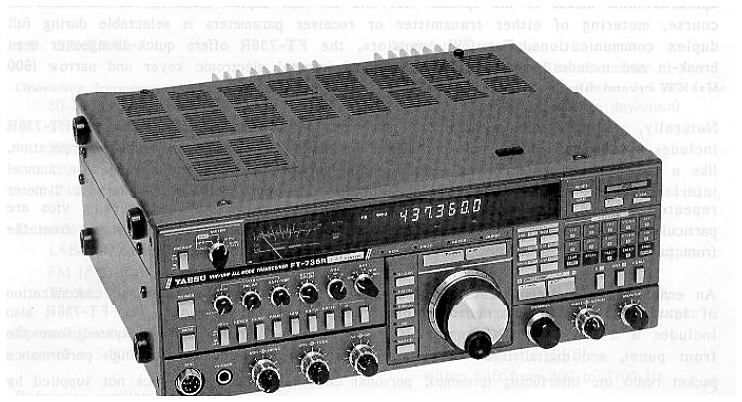
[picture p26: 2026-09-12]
Manual/figures/fig-radio-34.png

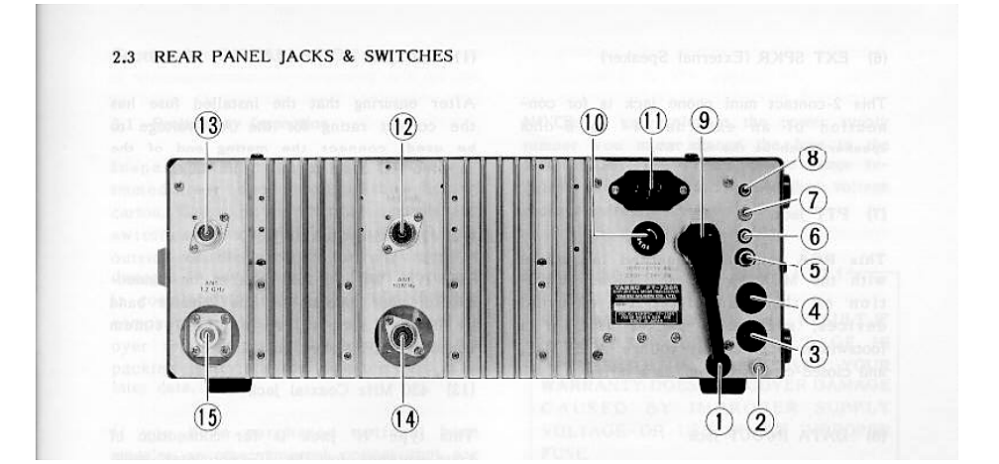
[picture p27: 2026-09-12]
Manual/figures/fig-rear.png

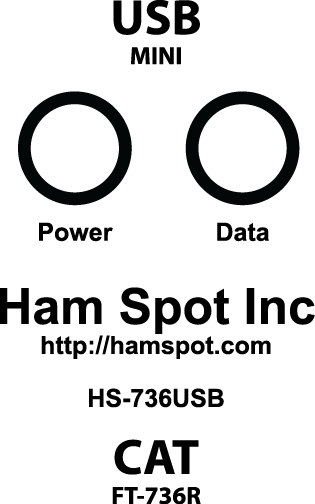
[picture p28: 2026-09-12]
Manual/figures/fig-faceplate.png

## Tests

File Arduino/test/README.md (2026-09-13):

# Tests

One command for unit tests plus every known opcode vs the internal state dump:

```
test/run_suite.sh
```

Against a programmed adapter (and the FT-736R if CAT is wired). This sends real CAT, including a short PTT ON then OFF:

```
test/run_suite.sh /dev/ttyUSB0
```

Host mapper only:

```
g++ -o /tmp/test_cat_map test/test_cat_map.cpp firmware/cat_map.cpp firmware/cat_frame.cpp firmware/gpio_logic.cpp firmware/encoder_logic.cpp firmware/proto_debounce.cpp
/tmp/test_cat_map
```

On a programmed Uno/Nano, without the FT-736R connected:

```
rigctl -m 1001 -r /dev/ttyUSB0 -s 4800
```

Hamlib model **1001** is FT-847. Set frequency and mode, then `f` / `m` should return the cache. `t` (PTT) should not time out.

With the radio: VFO + sat VFO, then the 736 CAT LED should light on CAT ON. See `docs/WIRING.md`.

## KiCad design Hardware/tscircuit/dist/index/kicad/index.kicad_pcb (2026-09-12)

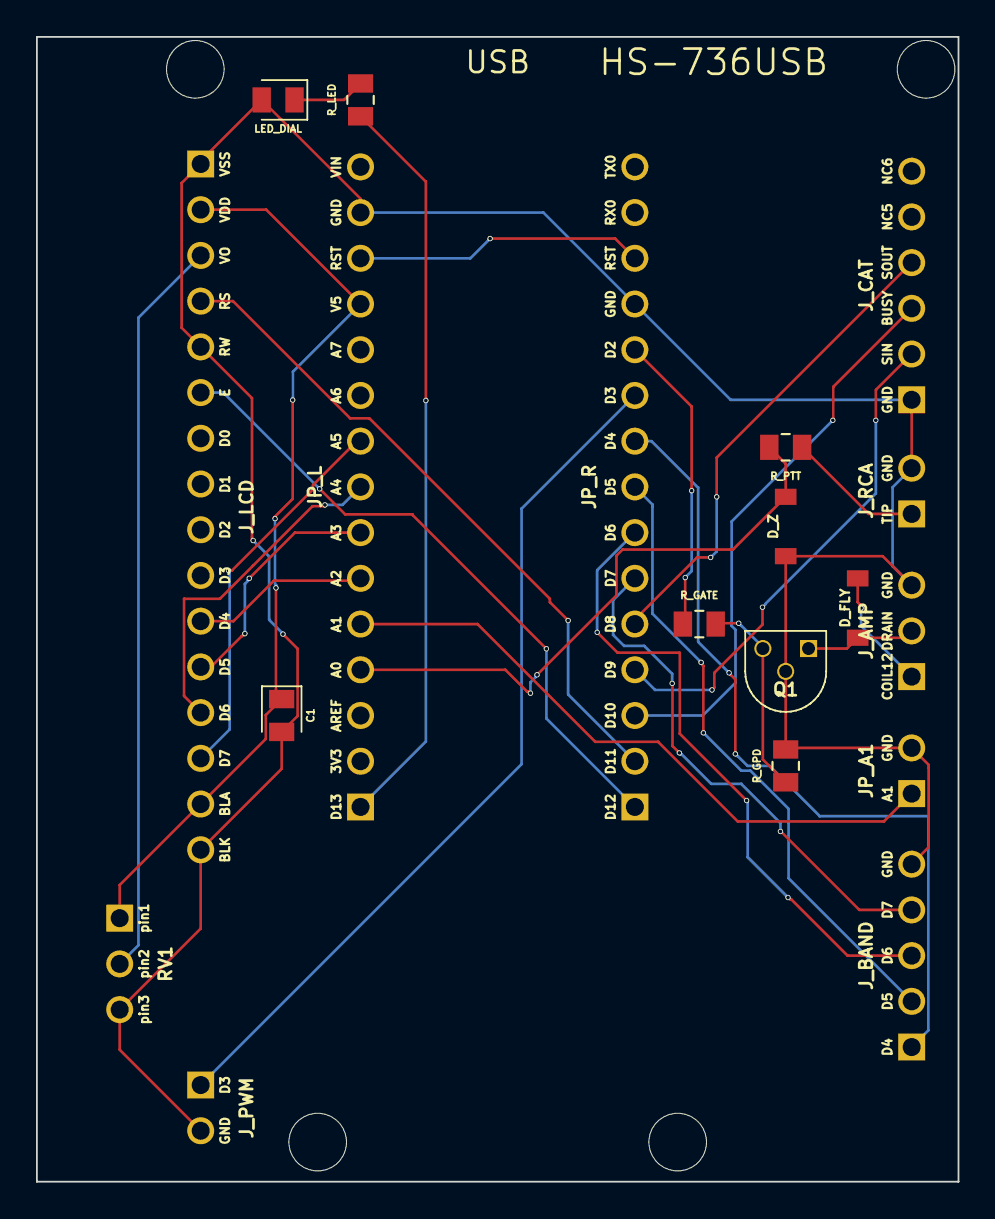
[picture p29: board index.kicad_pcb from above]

Board: 2 copper layers, 51.2 x 63.6 mm, 19 parts (0 on the bottom side), 27 nets.

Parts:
C1: 100nF; capacitor_cap0805
D_FLY: D; diode_sod123
D_Z: D; diode_sod123
JP_A1: JP_A1; pin_header_pinrow2_p2.54
JP_L: JP_L; pin_header_pinrow15_p2.54_female
JP_R: JP_R; pin_header_pinrow15_p2.54_female
J_AMP: J_AMP; pin_header_pinrow3_p2.54
J_BAND: J_BAND; pin_header_pinrow5_p2.54
J_CAT: J_CAT; pin_header_pinrow6_p2.54_female
J_LCD: J_LCD; pin_header_pinrow16_p2.54_female
J_PWM: J_PWM; pin_header_pinrow2_p2.54
J_RCA: J_RCA; pin_header_pinrow2_p2.54_female
LED_DIAL: LED; led_0805_color(green)
Q1: Q1; mosfet_to92
RV1: 10kΩ; potentiometer_pinrow3
R_GATE: 100Ω; resistor_res0805
R_GPD: 10kΩ; resistor_res0805
R_LED: 330Ω; resistor_res0805
R_PTT: 22kΩ; resistor_res0805

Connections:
A0: D_Z.2, JP_L.4, R_PTT.2
A1: JP_A1.1, JP_L.5
A2: JP_L.6, J_LCD.11
A3: JP_L.7, J_LCD.12
A4: JP_L.8, J_LCD.13
A5: JP_L.9, J_LCD.14
BUSY: JP_R.3, J_CAT.3
COIL12: D_FLY.2, J_AMP.1
D2: JP_R.11, R_GATE.1
D3: JP_R.10, J_PWM.1
D4: JP_R.9, J_BAND.1
D5: JP_R.8, J_BAND.2
D6: JP_R.7, J_BAND.3
D7: JP_R.6, J_BAND.4
D11: JP_R.2, J_LCD.4
D12: JP_R.1, J_LCD.6
D13: JP_L.1, R_LED.1
GND: C1.2, D_Z.1, JP_A1.2, JP_L.14, JP_R.12, J_AMP.3, J_BAND.5, J_CAT.1, J_LCD.1, J_LCD.5, J_LCD.16, J_PWM.2, J_RCA.2, LED_DIAL.2, Q1.2, RV1.3, R_GPD.2
LCD_VO: J_LCD.3, RV1.2
LED_A: LED_DIAL.1, R_LED.2
PTT_SW: D_FLY.1, J_AMP.2, Q1.1
QG: Q1.3, R_GATE.2, R_GPD.1
RCA: J_RCA.1, R_PTT.1
RST: JP_L.13, JP_R.13
SIN: JP_R.4, J_CAT.2
SOUT: JP_R.5, J_CAT.4
V5: C1.1, JP_L.12, J_LCD.2, J_LCD.15, RV1.1

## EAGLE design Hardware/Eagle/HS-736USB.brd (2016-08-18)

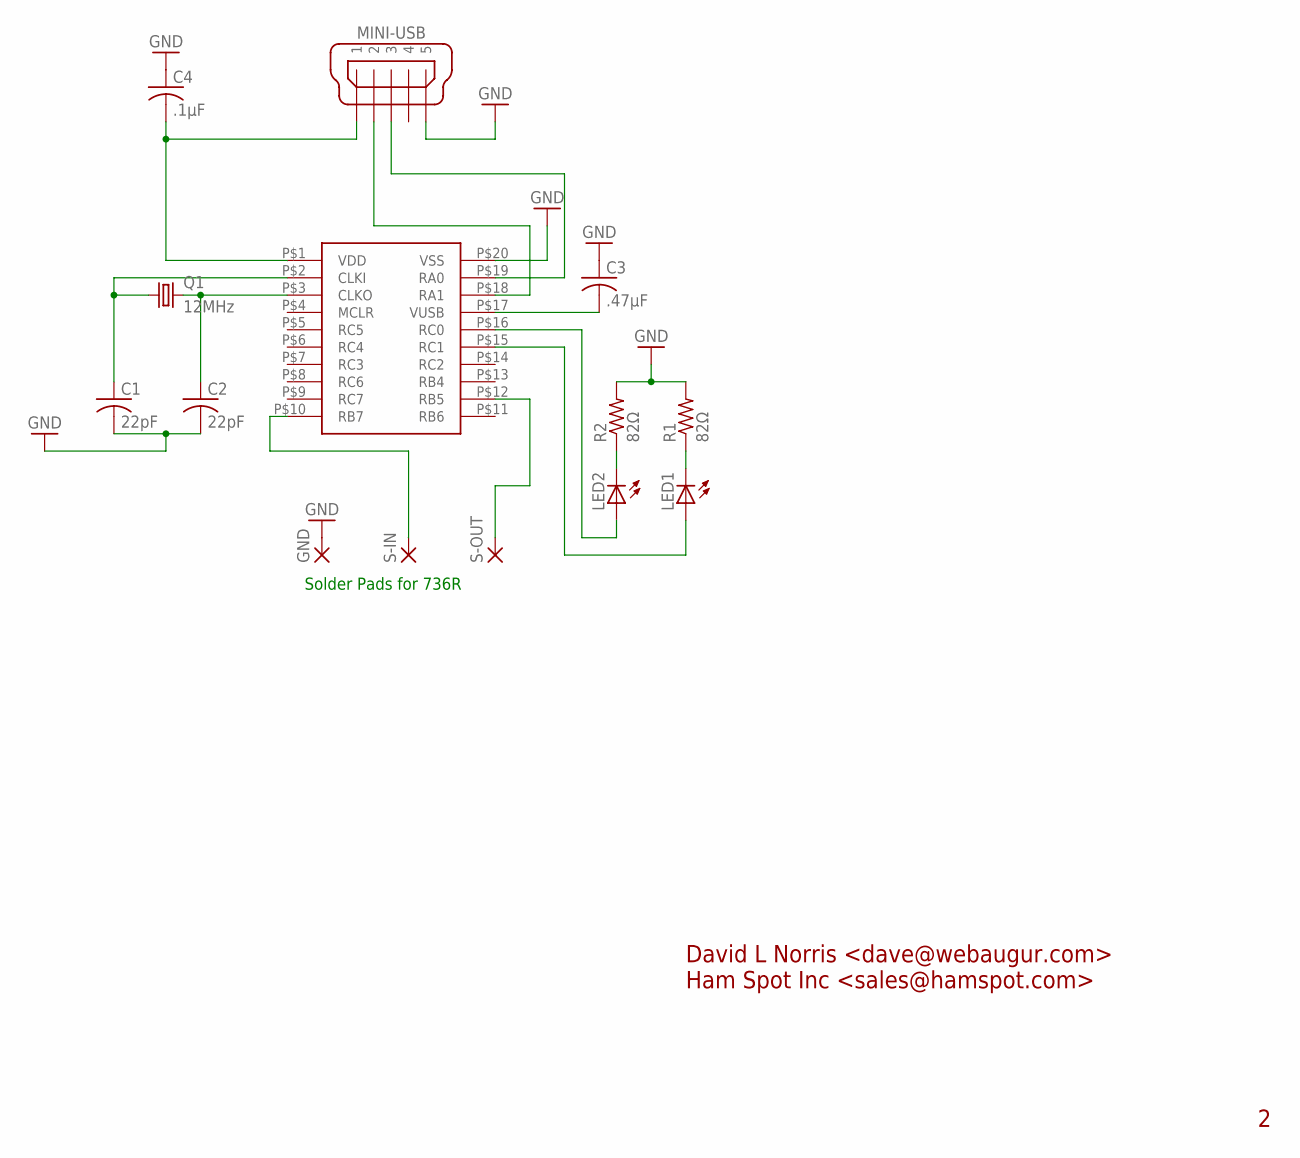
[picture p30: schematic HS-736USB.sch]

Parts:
C1, C2: 22pF; C1206
C3: .47µF; C1206
C4: .1µF; C1206
GND: 3,17/1,3
LED1, LED2: LED5MM
MINI-USB: MINI-USB-UX60-MB-5ST; UX60-MB-5ST
Q1: 12MHz; HC49/S
R1, R2: 82Ω; 0204V
S-IN: 3,17/1,3
S-OUT: 3,17/1,3
U$1: 14K50_DIP

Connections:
GND: C1.2, C2.2, C3.1, C4.1, GND.1, MINI-USB.5, R1.2, R2.2, U$1.P$20 (VSS)
unnamed: C2.1, Q1.2, U$1.P$3 (CLKO)
unnamed: C1.1, Q1.1, U$1.P$2 (CLKI)
unnamed: LED2.K (C), R2.1
unnamed: C4.2, MINI-USB.1, U$1.P$1 (VDD)
unnamed: LED1.K (C), R1.1
unnamed: C3.2, U$1.P$17 (VUSB)
unnamed: MINI-USB.2, U$1.P$18 (RA1)
unnamed: MINI-USB.3, U$1.P$19 (RA0)
unnamed: S-OUT.1, U$1.P$12 (RB5)
unnamed: S-IN.1, U$1.P$10 (RB7)
unnamed: LED2.A, U$1.P$16 (RC0)
unnamed: LED1.A, U$1.P$15 (RC1)

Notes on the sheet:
Solder Pads for 736R
David L Norris <dave@webaugur.com> Ham Spot Inc <sales@hamspot.com>

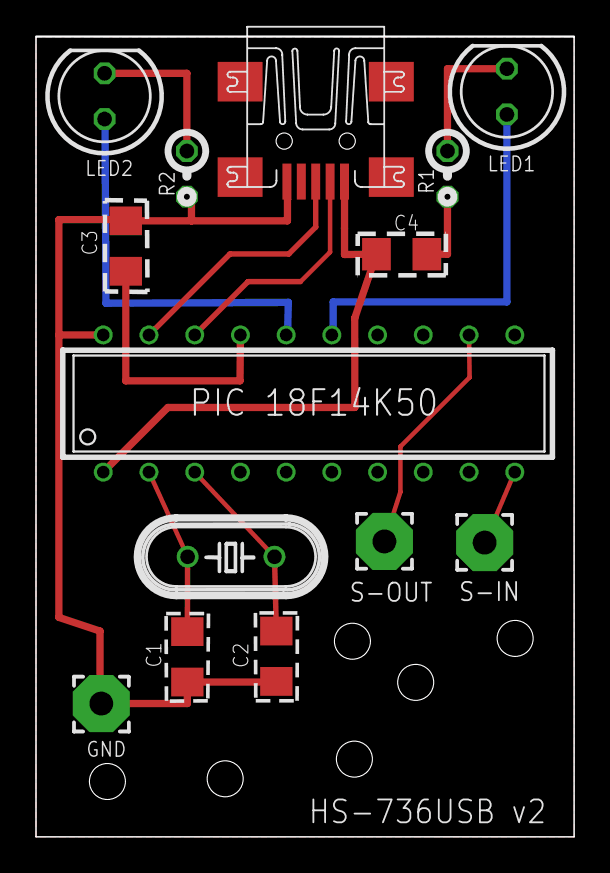
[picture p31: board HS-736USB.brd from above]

Board: 2 copper layers, 29.9 x 44.4 mm, 14 parts (0 on the bottom side), 13 nets.

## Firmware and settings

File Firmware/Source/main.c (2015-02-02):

/********************************************************************
 FileName:     main.c
 Dependencies: See INCLUDES section
 Processor:		PIC18 or PIC24 USB Microcontrollers
 Hardware:		The code is natively intended to be used on the following
 				hardware platforms: PICDEM™ FS USB Demo Board, 
 				PIC18F87J50 FS USB Plug-In Module, or
 				Explorer 16 + PIC24 USB PIM.  The firmware may be
 				modified for use on other USB platforms by editing the
 				HardwareProfile.h file.
 Complier:  	Microchip C18 (for PIC18) or C30 (for PIC24)
 Company:		Microchip Technology, Inc.

 Software License Agreement:

 The software supplied herewith by Microchip Technology Incorporated
 (the “Company”) for its PIC® Microcontroller is intended and
 supplied to you, the Company’s customer, for use solely and
 exclusively on Microchip PIC Microcontroller products. The
 software is owned by the Company and/or its supplier, and is
 protected under applicable copyright laws. All rights are reserved.
 Any use in violation of the foregoing restrictions may subject the
 user to criminal sanctions under applicable laws, as well as to
 civil liability for the breach of the terms and conditions of this
 license.

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
********************************************************************
 File Description:

 Change History:
  Rev   Date         Description
  1.0   11/19/2004   Initial release
  2.1   02/26/2007   Updated for simplicity and to use common
                     coding style
********************************************************************/

/** INCLUDES *******************************************************/
#include "./USB/usb.h"
#include "./USB/usb_function_cdc.h"

#include "HardwareProfile.h"

#if defined (__C30__) || defined(__C32__)
    #include "./uart2.h"
#endif

/** CONFIGURATION **************************************************/
#if defined(PICDEM_FS_USB)      // Configuration bits for PICDEM FS USB Demo Board (based on PIC18F4550)
        #pragma config PLLDIV   = 5         // (20 MHz crystal on PICDEM FS USB board)
        #pragma config CPUDIV   = OSC1_PLL2   
        #pragma config USBDIV   = 2         // Clock source from 96MHz PLL/2
        #pragma config FOSC     = HSPLL_HS
        #pragma config FCMEN    = OFF
        #pragma config IESO     = OFF
        #pragma config PWRT     = OFF
        #pragma config BOR      = ON
        #pragma config BORV     = 3
        #pragma config VREGEN   = ON      //USB Voltage Regulator
        #pragma config WDT      = OFF
        #pragma config WDTPS    = 32768
        #pragma config MCLRE    = ON
        #pragma config LPT1OSC  = OFF
        #pragma config PBADEN   = OFF
//      #pragma config CCP2MX   = ON
        #pragma config STVREN   = ON
        #pragma config LVP      = OFF
//      #pragma config ICPRT    = OFF       // Dedicated In-Circuit Debug/Programming
        #pragma config XINST    = OFF       // Extended Instruction Set
        #pragma config CP0      = OFF
        #pragma config CP1      = OFF
//      #pragma config CP2      = OFF
//      #pragma config CP3      = OFF
        #pragma config CPB      = OFF
//      #pragma config CPD      = OFF
        #pragma config WRT0     = OFF
        #pragma config WRT1     = OFF
//      #pragma config WRT2     = OFF
//      #pragma config WRT3     = OFF
        #pragma config WRTB     = OFF       // Boot Block Write Protection
        #pragma config WRTC     = OFF
//      #pragma config WRTD     = OFF
        #pragma config EBTR0    = OFF
        #pragma config EBTR1    = OFF
//      #pragma config EBTR2    = OFF
//      #pragma config EBTR3    = OFF
        #pragma config EBTRB    = OFF


#elif defined(PIC18F87J50_PIM)				// Configuration bits for PIC18F87J50 FS USB Plug-In Module board
        #pragma config XINST    = OFF   	// Extended instruction set
        #pragma config STVREN   = ON      	// Stack overflow reset
        #pragma config PLLDIV   = 3         // (12 MHz crystal used on this board)
        #pragma config WDTEN    = OFF      	// Watch Dog Timer (WDT)
        #pragma config CP0      = OFF      	// Code protect
        #pragma config CPUDIV   = OSC1      // OSC1 = divide by 1 mode
        #pragma config IESO     = OFF      	// Internal External (clock) Switchover
        #pragma config FCMEN    = OFF      	// Fail Safe Clock Monitor
        #pragma config FOSC     = HSPLL     // Firmware must also set OSCTUNE<PLLEN> to start PLL!
        #pragma config WDTPS    = 32768
//      #pragma config WAIT     = OFF      	// Commented choices are
//      #pragma config BW       = 16      	// only available on the
//      #pragma config MODE     = MM      	// 80 pin devices in the 
//      #pragma config EASHFT   = OFF      	// family.
        #pragma config MSSPMSK  = MSK5
//      #pragma config PMPMX    = DEFAULT
//      #pragma config ECCPMX   = DEFAULT
        #pragma config CCP2MX   = DEFAULT   

#elif defined(PIC18F46J50_PIM)
     #pragma config WDTEN = OFF          //WDT disabled (enabled by SWDTEN bit)
     #pragma config PLLDIV = 3           //Divide by 3 (12 MHz oscillator input)
     #pragma config STVREN = ON            //stack overflow/underflow reset enabled
     #pragma config XINST = OFF          //Extended instruction set disabled
     #pragma config CPUDIV = OSC1        //No CPU system clock divide
     #pragma config CP0 = OFF            //Program memory is not code-protected
     #pragma config OSC = HSPLL          //HS oscillator, PLL enabled, HSPLL used by USB
     #pragma config T1DIG = ON           //Sec Osc clock source may be selected
     #pragma config LPT1OSC = OFF        //high power Timer1 mode
     #pragma config FCMEN = OFF          //Fail-Safe Clock Monitor disabled
     #pragma config IESO = OFF           //Two-Speed Start-up disabled
     #pragma config WDTPS = 32768        //1:32768
     #pragma config DSWDTOSC = INTOSCREF //DSWDT uses INTOSC/INTRC as clock
     #pragma config RTCOSC = T1OSCREF    //RTCC uses T1OSC/T1CKI as clock
     #pragma config DSBOREN = OFF        //Zero-Power BOR disabled in Deep Sleep
     #pragma config DSWDTEN = OFF        //Disabled
     #pragma config DSWDTPS = 8192       //1:8,192 (8.5 seconds)
     #pragma config IOL1WAY = OFF        //IOLOCK bit can be set and cleared
     #pragma config MSSP7B_EN = MSK7     //7 Bit address masking
     #pragma config WPFP = PAGE_1        //Write Protect Program Flash Page 0
     #pragma config WPEND = PAGE_0       //Start protection at page 0
     #pragma config WPCFG = OFF          //Write/Erase last page protect Disabled
     #pragma config WPDIS = OFF          //WPFP[5:0], WPEND, and WPCFG bits ignored 
#elif defined(LOW_PIN_COUNT_USB_DEVELOPMENT_KIT)
        //14K50
        #pragma config CPUDIV = NOCLKDIV
        #pragma config USBDIV = OFF
        #pragma config FOSC   = HS
        #pragma config PLLEN  = ON
        #pragma config FCMEN  = OFF
        #pragma config IESO   = OFF
        #pragma config PWRTEN = OFF
        #pragma config BOREN  = OFF
        #pragma config BORV   = 30
//        #pragma config VREGEN = ON
        #pragma config WDTEN  = OFF
        #pragma config WDTPS  = 32768
        #pragma config MCLRE  = OFF
        #pragma config HFOFST = OFF
        #pragma config STVREN = ON
        #pragma config LVP    = OFF
        #pragma config XINST  = OFF
        #pragma config BBSIZ  = OFF
        #pragma config CP0    = OFF
        #pragma config CP1    = OFF
        #pragma config CPB    = OFF
        #pragma config WRT0   = OFF
        #pragma config WRT1   = OFF
        #pragma config WRTB   = OFF
        #pragma config WRTC   = OFF
        #pragma config EBTR0  = OFF
        #pragma config EBTR1  = OFF
        #pragma config EBTRB  = OFF       

#elif defined(EXPLORER_16)
    #ifdef __PIC24FJ256GB110__ //Defined by MPLAB when using 24FJ256GB110 device
        _CONFIG1( JTAGEN_OFF & GCP_OFF & GWRP_OFF & COE_OFF & FWDTEN_OFF & ICS_PGx2) 
        _CONFIG2( 0xF7FF & IESO_OFF & FCKSM_CSDCMD & OSCIOFNC_OFF & POSCMOD_HS & FNOSC_PRIPLL & PLLDIV_DIV2 & IOL1WAY_ON)
    #elif defined(__32MX460F512L__)
        #pragma config UPLLEN   = ON        // USB PLL Enabled
        #pragma config FPLLMUL  = MUL_15        // PLL Multiplier
        #pragma config UPLLIDIV = DIV_2         // USB PLL Input Divider
        #pragma config FPLLIDIV = DIV_2         // PLL Input Divider
        #pragma config FPLLODIV = DIV_1         // PLL Output Divider
        #pragma config FPBDIV   = DIV_1         // Peripheral Clock divisor
        #pragma config FWDTEN   = OFF           // Watchdog Timer
        #pragma config WDTPS    = PS1           // Watchdog Timer Postscale
        #pragma config FCKSM    = CSDCMD        // Clock Switching & Fail Safe Clock Monitor
        #pragma config OSCIOFNC = OFF           // CLKO Enable
        #pragma config POSCMOD  = HS            // Primary Oscillator
        #pragma config IESO     = OFF           // Internal/External Switch-over
        #pragma config FSOSCEN  = OFF           // Secondary Oscillator Enable (KLO was off)
        #pragma config FNOSC    = PRIPLL        // Oscillator Selection
        #pragma config CP       = OFF           // Code Protect
        #pragma config BWP      = OFF           // Boot Flash Write Protect
        #pragma config PWP      = OFF           // Program Flash Write Protect
        #pragma config ICESEL   = ICS_PGx2      // ICE/ICD Comm Channel Select
        #pragma config DEBUG    = ON            // Background Debugger Enable
    #else
        #error No hardware board defined, see "HardwareProfile.h" and __FILE__
    #endif
#else
    #error No hardware board defined, see "HardwareProfile.h" and __FILE__
#endif

/** I N C L U D E S **********************************************************/

#include "GenericTypeDefs.h"
#include "Compiler.h"
#include "usb_config.h"
#include "USB/usb_device.h"
#include "USB/usb.h"
#include "HardwareProfile.h"

/** V A R I A B L E S ********************************************************/
#pragma udata
char USB_Out_Buffer[CDC_DATA_OUT_EP_SIZE];
char RS232_Out_Data[CDC_DATA_IN_EP_SIZE];

unsigned char  NextUSBOut;
unsigned char    NextUSBOut;
//char RS232_In_Data;
unsigned char    LastRS232Out;  // Number of characters in the buffer
unsigned char    RS232cp;       // current position within the buffer
unsigned char RS232_Out_Data_Rdy = 0;
char psn = 0;
char cmd[10];
char freqbuffer[5] = { 0x14, 0x50, 0x00, 0x00, 0x08};
char freqbufferRX[5] = { 0x14, 0x50, 0x00, 0x00, 0x00};
char freqbufferTX[5] = { 0x44, 0x00, 0x00, 0x00, 0x00};
char RXstatusbuffer[5] = { 0x80, 0x80, 0x80, 0x80, 0xE7};  
char TXstatusbuffer[5] = { 0x80, 0x80, 0x80, 0x80, 0xF7}; 
char Tone[38] = { 0x1E,0X20,0X22,0X24,0X26,0X28,0X2A,0X2C,0X2E,0X30,0X32,0X34,0X36,0X38,0X16,0X1A,0X1F,
                  0X21,0X23,0X25,0X27,0X29,0X2B,0X2D,0X2F,0X31,0X33,0X35,0X37,0X39,0X18,0X1C,0X13,0X15,
						0X17,0X19,0X1B,0X1D };
char x = 0;
USB_HANDLE  lastTransmission;

//BOOL stringPrinted;


/** P R I V A T E  P R O T O T Y P E S ***************************************/
static void InitializeSystem(void);
void ProcessIO(void);
void USBDeviceTasks(void);
void YourHighPriorityISRCode();
void YourLowPriorityISRCode();
void BlinkUSBStatus(void);
void UserInit(void);
void InitializeUSART(void);
void putcUSART(char c);
void To736(void);
unsigned char getcUSART ();
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
int main(void)
#endif
{   
    InitializeSystem();

    #if defined(USB_INTERRUPT)
        USBDeviceAttach();
    #endif

    while(1)
    {
        #if defined(USB_POLLING)
		// Check bus status and service USB interrupts.
        USBDeviceTasks(); // Interrupt or polling method.  If using polling, must call
        				  // this function periodically.  This function will take care
        				  // of processing and responding to SETUP transactions 
        				  // (such as during the enumeration process when you first
        				  // plug in).  USB hosts require that USB devices should accept
        				  // and process SETUP packets in a timely fashion.  Therefore,
        				  // when using polling, this function should be called 
        				  // frequently (such as once about every 100 microseconds) at any
        				  // time that a SETUP packet might reasonably be expected to
        				  // be sent by the host to your device.  In most cases, the
        				  // USBDeviceTasks() function does not take very long to
        				  // execute (~50 instruction cycles) before it returns.
        #endif
    				  

		// Application-specific tasks.
		// Application related code may be added here, or in the ProcessIO() function.
        ProcessIO();        
    }//end while
}//end main


/********************************************************************
 * Function:        static void InitializeSystem(void)
 *
 * PreCondition:    None
 *
 * Input:           None
 *
 * Output:          None
 *
 * Side Effects:    None
 *
 * Overview:        InitializeSystem is a centralize initialization
 *                  routine. All required USB initialization routines
 *                  are called from here.
 *
 *                  User application initialization routine should
 *                  also be called from here.                  
 *
 * Note:            None
 *******************************************************************/
static void InitializeSystem(void)
{
    #if (defined(__18CXX) & !defined(PIC18F87J50_PIM))
        ADCON1 |= 0x0F;                 // Default all pins to digital
    #elif defined(__C30__)
        AD1PCFGL = 0xFFFF;
    #elif defined(__C32__)
        AD1PCFG = 0xFFFF;
    #endif

    #if defined(PIC18F87J50_PIM) || defined(PIC18F46J50_PIM)
	//On the PIC18F87J50 Family of USB microcontrollers, the PLL will not power up and be enabled
	//by default, even if a PLL enabled oscillator configuration is selected (such as HS+PLL).
	//This allows the device to power up at a lower initial operating frequency, which can be
	//advantageous when powered from a source which is not gauranteed to be adequate for 48MHz
	//operation.  On these devices, user firmware needs to manually set the OSCTUNE<PLLEN> bit to
	//power up the PLL.
    {
        unsigned int pll_startup_counter = 600;
        OSCTUNEbits.PLLEN = 1;  //Enable the PLL and wait 2+ms until the PLL locks before enabling USB module
        while(pll_startup_counter--);
    }
    //Device switches over automatically to PLL output after PLL is locked and ready.
    #endif

    #if defined(PIC18F87J50_PIM)
	//Configure all I/O pins to use digital input buffers.  The PIC18F87J50 Family devices
	//use the ANCONx registers to control this, which is different from other devices which
	//use the ADCON1 register for this purpose.
    WDTCONbits.ADSHR = 1;			// Select alternate SFR location to access ANCONx registers
    ANCON0 = 0xFF;                  // Default all pins to digital
    ANCON1 = 0xFF;                  // Default all pins to digital
    WDTCONbits.ADSHR = 0;			// Select normal SFR locations
    #endif

    #if defined(PIC18F46J50_PIM)
	//Configure all I/O pins to use digital input buffers.  The PIC18F87J50 Family devices
	//use the ANCONx registers to control this, which is different from other devices which
	//use the ADCON1 register for this purpose.
    ANCON0 = 0xFF;                  // Default all pins to digital
    ANCON1 = 0xFF;                  // Default all pins to digital
    #endif
    
//	The USB specifications require that USB peripheral devices must never source
//	current onto the Vbus pin.  Additionally, USB peripherals should not source
//	current on D+ or D- when the host/hub is not actively powering the Vbus line.
//	When designing a self powered (as opposed to bus powered) USB peripheral
//	device, the firmware should make sure not to turn on the USB module and D+
//	or D- pull up resistor unless Vbus is actively powered.  Therefore, the
//	firmware needs some means to detect when Vbus is being powered by the host.
//	A 5V tolerant I/O pin can be connected to Vbus (through a resistor), and
// 	can be used to detect when Vbus is high (host actively powering), or low
//	(host is shut down or otherwise not supplying power).  The USB firmware
// 	can then periodically poll this I/O pin to know when it is okay to turn on
//	the USB module/D+/D- pull up resistor.  When designing a purely bus powered
//	peripheral device, it is not possible to source current on D+ or D- when the
//	host is not actively providing power on Vbus. Therefore, implementing this
//	bus sense feature is optional.  This firmware can be made to use this bus
//	sense feature by making sure "USE_USB_BUS_SENSE_IO" has been defined in the
//	HardwareProfile.h file.    
    #if defined(USE_USB_BUS_SENSE_IO)
    tris_usb_bus_sense = INPUT_PIN; // See HardwareProfile.h
    #endif
    
//	If the host PC sends a GetStatus (device) request, the firmware must respond
//	and let the host know if the USB peripheral device is currently bus powered
//	or self powered.  See chapter 9 in the official USB specifications for details
//	regarding this request.  If the peripheral device is capable of being both
//	self and bus powered, it should not return a hard coded value for this request.
//	Instead, firmware should check if it is currently self or bus powered, and
//	respond accordingly.  If the hardware has been configured like demonstrated
//	on the PICDEM FS USB Demo Board, an I/O pin can be polled to determine the
//	currently selected power source.  On the PICDEM FS USB Demo Board, "RA2" 
//	is used for	this purpose.  If using this feature, make sure "USE_SELF_POWER_SENSE_IO"
//	has been defined in HardwareProfile.h, and that an appropriate I/O pin has been mapped
//	to it in HardwareProfile.h.
    #if defined(USE_SELF_POWER_SENSE_IO)
    tris_self_power = INPUT_PIN;	// See HardwareProfile.h
    #endif
    
    UserInit();

    USBDeviceInit();	//usb_device.c.  Initializes USB module SFRs and firmware
    					//variables to known states.
}//end InitializeSystem



/******************************************************************************
 * Function:        void UserInit(void)
 *
 * PreCondition:    None
 *
 * Input:           None
 *
 * Output:          None
 *
 * Side Effects:    None
 *
 * Overview:        This routine should take care of all of the demo code
 *                  initialization that is required.
 *
 * Note:            
 *
 *****************************************************************************/
void UserInit(void)
{
	unsigned char i;
    InitializeUSART();

// 	 Initialize the arrays
	for (i=0; i<sizeof(USB_Out_Buffer); i++)
    {
		USB_Out_Buffer[i] = 0;
    }

	NextUSBOut = 0;
	LastRS232Out = 0;
	lastTransmission = 0;

	mInitAllLEDs();
}//end UserInit

/******************************************************************************
 * Function:        void InitializeUSART(void)
 *
 * PreCondition:    None
 *
 * Input:           None
 *
 * Output:          None
 *
 * Side Effects:    None
 *
 * Overview:        This routine initializes the UART to 19200
 *
 * Note:            
 *
 *****************************************************************************/
void InitializeUSART(void)
{
    
    //ADD C18 PIC18F14K50 EUSART INITIALIZATION CODE HERE
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

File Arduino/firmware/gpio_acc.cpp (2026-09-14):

#include "gpio_acc.h"
#include "hs736_features.h"

#include <Arduino.h>
#if HS736_USE_MCP
#include <avr/interrupt.h>
#include <string.h>
#include "encoder_logic.h"
#include "mcp23017.h"
#endif

#include "cat_map.h"
#include "gpio_logic.h"
#include "lcd_ui.h"
#include "radio_uart.h"

/* PTT MOSFET gate. HIGH = TX (low-side switch on). */
static const uint8_t k_ptt_out = 2;
/* S-meter PWM. Timer2 OC2B — not Timer1 (AltSoftSerial). */
static const uint8_t k_smeter_pwm = 3;
static const uint8_t k_hot_50 = 4;
static const uint8_t k_hot_144 = 5;
static const uint8_t k_hot_220 = 6;
static const uint8_t k_hot_430 = 7;
/* CAT pin 3 BUSY. INPUT_PULLUP; LOW = carrier / squelch open. */
static const uint8_t k_busy = 10;
static const uint8_t k_dialect_led = 13;
/*
 * Optional PTT sense from the radio RCA (MOX / mic / footswitch).
 * Active LOW after 22k + 5.1 V zener (see docs/WIRING.md). INPUT_PULLUP
 * so an unconnected jack reads RX.
 */
static const uint8_t k_ptt_in = A0;
#if HS736_USE_MCP
/* MCP INT. D11 / PB3 / PCINT3. */
static const uint8_t k_mcp_int = 11;
#if HS736_MCP == 8
/* Shaft switch: 08 has no spare GPIO after LCD+A/B. D12 / PB4 / PCINT4. */
static const uint8_t k_enc_sw = 12;
#endif
#endif

static const uint8_t k_meter_cmd[5] = {0x00, 0x00, 0x00, 0x00, 0xF7};
static const uint16_t k_meter_reply_ms = 400;

enum {
    METER_IDLE = 0,
    METER_WAIT_TX,
    METER_WAIT_RX
};

static uint8_t s_meter_state;
static uint32_t s_last_poll_ms;
static uint32_t s_last_tx_ms;
static uint32_t s_rx_deadline_ms;
static uint8_t s_pwm;
static uint16_t s_shown_q8;
static uint32_t s_slew_last_ms;
static uint8_t s_rxn;
static uint8_t s_rxb[5];
#if HS736_USE_MCP
static volatile uint8_t s_enc_irq;
static uint8_t s_quad_prev;
static int8_t s_quad_acc;
static encoder_btn_t s_btn;
static uint8_t s_pend_n;
static uint8_t s_pend[CAT_MAX_RADIO_FRAMES][CAT_BLOCK];

ISR(PCINT0_vect)
{
    s_enc_irq = 1;
}

static void pend_frames(const cat_result_t *r)
{
    uint8_t i;

    for (i = 0; i < r->n_radio && s_pend_n < CAT_MAX_RADIO_FRAMES; i++) {
        memcpy(s_pend[s_pend_n], r->radio[i], CAT_BLOCK);
        s_pend_n++;
    }
}

static void flush_pend(void)
{
    while (s_pend_n > 0 && radio_uart_queue(s_pend[0])) {
        uint8_t i;
        s_pend_n--;
        for (i = 0; i < s_pend_n; i++) {
            memcpy(s_pend[i], s_pend[i + 1], CAT_BLOCK);
        }
    }
}

static uint8_t enc_nibble_now(void)
{
    uint8_t c;

    c = lcd_ui_cursor();
    if (c == ENC_CURSOR_DEFAULT) {
        return encoder_default_nibble(cat_mode_main());
    }
    return c;
}

static void encoder_service(uint32_t now_ms)
{
    uint8_t b;
    uint8_t ab;
    uint8_t rel;
    int8_t q;
    encoder_btn_ev_t ev;
    cat_result_t r;

    b = mcp23017_read_b();
    ab = (uint8_t)(((b & MCP_ENC_B) ? 2u : 0u) | ((b & MCP_ENC_A) ? 1u : 0u));
    q = encoder_quad_step(&s_quad_prev, ab);
    s_quad_acc = (int8_t)(s_quad_acc + q);
    if (s_quad_acc >= 4 || s_quad_acc <= -4) {
        cat_map_knob_freq((int8_t)(s_quad_acc > 0 ? 1 : -1), enc_nibble_now(), &r);
        pend_frames(&r);
        s_quad_acc = 0;
        lcd_ui_set_cursor(lcd_ui_cursor());
    }

    rel = (b & MCP_ENC_SW) ? 1u : 0u;
    ev = encoder_btn_poll(&s_btn, rel, now_ms);
    if (ev == ENC_BTN_SHORT) {
        lcd_ui_set_cursor(encoder_cursor_next(lcd_ui_cursor()));
    } else if (ev == ENC_BTN_LONG) {
        cat_map_knob_mode(&r);
        pend_frames(&r);
        lcd_ui_set_cursor(ENC_CURSOR_DEFAULT);
    }
}
#endif /* HS736_USE_MCP */

static bool hw_ptt_low(void)
{
    return digitalRead(k_ptt_in) == LOW;
}

static bool keyed_now(void)
{
    return cat_ptt() || hw_ptt_low();
}

/* LOW on BUSY = squelch open (carrier). Floating pull-up = closed. */
static bool sql_closed_now(void)
{
    return digitalRead(k_busy) != LOW;
}

static void write_bands(uint8_t mask)
{
    digitalWrite(k_hot_50, (mask & CAT_BAND_50) ? HIGH : LOW);
    digitalWrite(k_hot_144, (mask & CAT_BAND_144) ? HIGH : LOW);
    digitalWrite(k_hot_220, (mask & CAT_BAND_220) ? HIGH : LOW);
    digitalWrite(k_hot_430, (mask & CAT_BAND_430) ? HIGH : LOW);
}
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

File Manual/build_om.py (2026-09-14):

#!/usr/bin/env python3
"""Build the HS-736USB operating manual (Yaesu OM visual style).

Run from anywhere:
    python3 Manual/build_om.py

Output:
    Manual/HS-736USB-Operating-Manual.pdf

FT-736R photographs are short excerpts from the Yaesu FT-736R Operating
Manual, used here for identification and instruction. They remain
copyright Yaesu Musen Co., Ltd. This file is not a Yaesu publication.
"""

from __future__ import annotations

import os
from reportlab.lib import colors
from reportlab.lib.enums import TA_CENTER, TA_JUSTIFY, TA_LEFT, TA_RIGHT
from reportlab.lib.pagesizes import letter
from reportlab.lib.styles import ParagraphStyle, getSampleStyleSheet
from reportlab.lib.units import inch
from reportlab.platypus import (
    BaseDocTemplate,
    Frame,
    HRFlowable,
    Image,
    KeepTogether,
    NextPageTemplate,
    PageBreak,
    PageTemplate,
    Paragraph,
    Spacer,
    Table,
    TableStyle,
)
from reportlab.pdfgen.canvas import Canvas
from reportlab.lib.utils import ImageReader

HERE = os.path.dirname(os.path.abspath(__file__))
FIG = os.path.join(HERE, "figures")
OUT = os.path.join(HERE, "HS-736USB-Operating-Manual.pdf")

PAGE_W, PAGE_H = letter
MARGIN_L = 0.72 * inch
MARGIN_R = 0.72 * inch
MARGIN_T = 0.78 * inch
MARGIN_B = 0.72 * inch
COL_W = PAGE_W - MARGIN_L - MARGIN_R

GREY_BAR = colors.Color(0.42, 0.42, 0.44)
NEAR_BLACK = colors.Color(0.08, 0.08, 0.08)
RULE = colors.Color(0.12, 0.12, 0.12)
WARN_BG = colors.Color(0.96, 0.96, 0.96)
LIGHT = colors.Color(0.93, 0.93, 0.93)
HEAD_GREY = colors.Color(0.35, 0.35, 0.37)


def fig_path(name: str) -> str:
    p = os.path.join(FIG, name)
    if not os.path.isfile(p):
        raise FileNotFoundError(p)
    return p


def sized_image(name: str, max_w: float, max_h: float | None = None) -> Image:
    path = fig_path(name)
    ir = ImageReader(path)
    iw, ih = ir.getSize()
    aspect = ih / float(iw)
    w = max_w
    h = w * aspect
    if max_h is not None and h > max_h:
        h = max_h
        w = h / aspect
    img = Image(path, width=w, height=h)
    img.hAlign = "CENTER"
    return img


def make_styles():
    ss = getSampleStyleSheet()
    styles = {
        "body": ParagraphStyle(
            "OMBody",
            parent=ss["Normal"],
            fontName="Helvetica",
            fontSize=9.5,
            leading=12.4,
            alignment=TA_JUSTIFY,
            textColor=NEAR_BLACK,
            spaceAfter=8,
        ),
        "bodyleft": ParagraphStyle(
            "OMBodyLeft",
            parent=ss["Normal"],
            fontName="Helvetica",
            fontSize=9.5,
            leading=12.4,
            alignment=TA_LEFT,
            textColor=NEAR_BLACK,
            spaceAfter=8,
        ),
        "section": ParagraphStyle(
            "OMSection",
            parent=ss["Normal"],
            fontName="Helvetica-Bold",
            fontSize=11,
            leading=14,
            textColor=NEAR_BLACK,
            spaceBefore=4,
            spaceAfter=4,
            keepWithNext=True,
        ),
        "sub": ParagraphStyle(
            "OMSub",
            parent=ss["Normal"],
            fontName="Helvetica-Bold",
            fontSize=10,
            leading=13,
            textColor=NEAR_BLACK,
            spaceBefore=10,
            spaceAfter=5,
            keepWithNext=True,
        ),
        "item": ParagraphStyle(
            "OMItem",
            parent=ss["Normal"],
            fontName="Helvetica-Bold",
            fontSize=9.5,
            leading=12,
            textColor=NEAR_BLACK,
            spaceBefore=6,
            spaceAfter=2,
        ),
        "caption": ParagraphStyle(
            "OMCaption",
            parent=ss["Normal"],
            fontName="Helvetica-Oblique",
            fontSize=8,
            leading=10.2,
            alignment=TA_CENTER,
            textColor=HEAD_GREY,
            spaceBefore=3,
            spaceAfter=10,
        ),
        "toc": ParagraphStyle(
            "OMToc",
            parent=ss["Normal"],
            fontName="Helvetica",
            fontSize=10,
            leading=16,
            textColor=NEAR_BLACK,
        ),
        "cell": ParagraphStyle(
            "OMCell",
            parent=ss["Normal"],
            fontName="Helvetica",
            fontSize=8.2,
            leading=10.6,
            textColor=NEAR_BLACK,
        ),
        "cellb": ParagraphStyle(
            "OMCellB",
            parent=ss["Normal"],
            fontName="Helvetica-Bold",
            fontSize=8.2,
            leading=10.6,
            textColor=NEAR_BLACK,
        ),
        "warn": ParagraphStyle(
            "OMWarn",
            parent=ss["Normal"],
            fontName="Helvetica-Bold",
            fontSize=8.4,
            leading=11.2,
            alignment=TA_CENTER,
            textColor=NEAR_BLACK,
        ),
        "small": ParagraphStyle(
            "OMSmall",
            parent=ss["Normal"],
            fontName="Helvetica",
            fontSize=8.2,
            leading=10.8,
            alignment=TA_JUSTIFY,
            textColor=NEAR_BLACK,
            spaceAfter=6,
        ),
        "center": ParagraphStyle(
            "OMCenter",
            parent=ss["Normal"],
            fontName="Helvetica",
            fontSize=9.5,
            leading=12.4,
            alignment=TA_CENTER,
            textColor=NEAR_BLACK,
            spaceAfter=8,
        ),
        "coversub": ParagraphStyle(
            "OMCoverSub",
            parent=ss["Normal"],
            fontName="Helvetica",
            fontSize=11,
            leading=14,
            alignment=TA_CENTER,
            textColor=NEAR_BLACK,
        ),
    }
    return styles


S = make_styles()


def P(text: str, style: str = "body") -> Paragraph:
    return Paragraph(text, S[style])


def section(title: str):
    return KeepTogether(
        [
            P(title, "section"),
            HRFlowable(
                width="100%",
                thickness=1.15,
                color=RULE,
                spaceBefore=0,
                spaceAfter=8,
            ),
        ]
    )


def caption(text: str) -> Paragraph:
    return P(text, "caption")


def figure(name: str, cap: str, max_w: float, max_h: float | None = None):
    return KeepTogether([sized_image(name, max_w, max_h), caption(cap)])
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

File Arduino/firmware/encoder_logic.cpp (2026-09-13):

#include "encoder_logic.h"

static const uint8_t k_modes[] = {
    0x04, 0x88, 0x08, 0x00, 0x01, 0x82, 0x02
};

#define K_MODES_N ((uint8_t)(sizeof(k_modes) / sizeof(k_modes[0])))

bool encoder_is_amfm(uint8_t mode)
{
    return mode == 0x04u || mode == 0x08u || mode == 0x88u;
}

uint8_t encoder_default_nibble(uint8_t mode)
{
    /* 1 kHz = nibble 5; 100 Hz = nibble 6. */
    return encoder_is_amfm(mode) ? 5u : 6u;
}

uint8_t encoder_next_mode(uint8_t mode)
{
    uint8_t i;

    for (i = 0; i < K_MODES_N; i++) {
        if (k_modes[i] == mode) {
            return k_modes[(uint8_t)((i + 1u) % K_MODES_N)];
        }
    }
    return k_modes[0];
}

uint8_t encoder_cursor_next(uint8_t cursor)
{
    if (cursor == ENC_CURSOR_DEFAULT || cursor >= ENC_NIBBLE_MAX) {
        return 0;
    }
    return (uint8_t)(cursor + 1u);
}

void encoder_add_nibble(uint8_t bcd[4], uint8_t nibble, int8_t dir)
{
    uint8_t i;
    uint8_t nib[8];
    int8_t d;

    if (nibble > ENC_NIBBLE_MAX || dir == 0) {
        return;
    }
    for (i = 0; i < 8; i++) {
        nib[i] = (uint8_t)((bcd[i / 2] >> ((i & 1u) ? 0 : 4)) & 0x0Fu);
    }
    d = (dir > 0) ? 1 : -1;
    i = nibble;
    while (1) {
        int8_t v = (int8_t)nib[i] + d;
        if (v > 9) {
            nib[i] = 0;
            d = 1;
            if (i == 0) {
                break;
            }
            i--;
            continue;
        }
        if (v < 0) {
            nib[i] = 9;
            d = -1;
            if (i == 0) {
                nib[i] = 0;
                break;
            }
            i--;
            continue;
        }
        nib[i] = (uint8_t)v;
        break;
    }
    for (i = 0; i < 4; i++) {
        bcd[i] = (uint8_t)((nib[i * 2] << 4) | nib[i * 2 + 1]);
    }
}

int8_t encoder_quad_step(uint8_t *prev, uint8_t ab)
{
    /* Gray: 00 -> 01 -> 11 -> 10 -> 00 is CW (+1) for many KY-040. */
    static const int8_t k_tab[16] = {
        0, 1, -1, 0, -1, 0, 0, 1, 1, 0, 0, -1, 0, -1, 1, 0
    };
    uint8_t idx;
    int8_t s;

    ab = (uint8_t)(ab & 3u);
    idx = (uint8_t)((*prev << 2) | ab);
    *prev = ab;
    s = k_tab[idx];
    return s;
}

void encoder_btn_init(encoder_btn_t *st, uint8_t released)
{
    st->stable = released ? 1u : 0u;
    st->armed = 0;
    st->long_done = 0;
    st->t_edge = 0;
    st->t_down = 0;
}
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

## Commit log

2015-02-02 Initial Import of Ham Spot HS-736USB Source Code and Hardware Design Files. Version 1.0 hardware interface.
    [HS-736USB.brd, HS-736USB.sch]
2015-02-02 Added makercase.com cabinet plans. Dimension only. AI/SVG files will later include holes for USB, cable, LEDs, etc.
2015-02-02 Added USB status LED indicators to the schematic and board layout. Refactored the silkscreen layers to be less cluttered and within boundaries.
    [HS-736USB.brd, HS-736USB.sch]
2016-08-18 Updated schematic and board for a small board run August 2016. Added missing Artwork for the various enclosure designs and board renderings.
    [HS-736RUSB-Enclosure.AMF, HS-736RUSB-Enclosure.skp, HS-736RUSB-Enclosure.stl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]
2016-08-18 Moved files around to the appropriate folders.
    [HS-736RUSB-Enclosure.AMF, HS-736RUSB-Enclosure.skp, HS-736RUSB-Enclosure.stl]
2026-09-12 Add ATmega328 Arduino port of the FT-847 to FT-736R CAT translator.
    Keeps the PIC firmware and Eagle files. New Arduino/ tree ports N6BIL's
    ProcessIO mapping, adds native-736 passthrough (A1 IRQ or CAT opcode),
    PTT/band GPIO, slewed S-meter PWM, and a host opcode test suite.
2026-09-12 Add Arduino LCD UI, Nano carrier, and operating manual for v2.0.0.
    Keep the PIC tree. Arduino firmware adds the 16x2 LCD, dialect LED, BUSY
    on D10, and GPIO as documented. Hardware/tscircuit is the Nano carrier
    (schematic, autorouted PCB, KiCad export). Manual/ is the Yaesu-style OM
    with PIC Fig. 2 and Nano Fig. 2A/10.
    [index.kicad_pcb, index.kicad_sch]
2026-09-13 Add optional MCP23017 LCD and rotary encoder.
    Bare HD44780 and KY-040 sit on the expander (I2C A4/A5). HS736_USE_MCP23017
    in hs736_features.h (or -DHS736_USE_MCP23017=0) drops LCD, encoder, and I2C.
    Band/PTT/PWM/CAT unchanged. Encoder steps 1 kHz in AM/FM, 100 Hz otherwise;
    short press moves the digit cursor, long press cycles mode.
    [build_om.py, cat_map.cpp, encoder_logic.cpp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]
2026-09-14 Added MCP 8 port option and bumped the encoder shaft switch to Mega328 PCINT.

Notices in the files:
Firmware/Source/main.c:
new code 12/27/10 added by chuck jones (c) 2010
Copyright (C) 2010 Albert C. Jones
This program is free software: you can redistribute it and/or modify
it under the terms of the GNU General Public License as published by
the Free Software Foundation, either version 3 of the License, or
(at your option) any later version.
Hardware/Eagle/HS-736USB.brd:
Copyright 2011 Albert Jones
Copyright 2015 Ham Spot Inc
